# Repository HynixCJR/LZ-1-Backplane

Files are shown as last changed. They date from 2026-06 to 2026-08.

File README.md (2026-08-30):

# LAZARUS-1 Backplane PCB
LAZARUS-1 is a 2U rackmount server designed to support decommissioned laptops and SFF (Mini-ITX) desktop/server motherboards. The system consists of the following main components:
1. Sheet metal + 3D-printed chassis (TBD)
2. Backplane PCB (here)
3. [Front-panel breakout PCB](https://github.com/HynixCJR/serverv2_front_panel_breakout)

> [!WARNING]
> This PCB design is currently a work in progress. The initial schematic design has been created, and revisions have been made to most of the schematic; however, the PCB remains incomplete as of this time.

> [!TIP]
> I did not use any AI to write this documentation! All words you see here are written entirely by me (Matthew Kong).

This repository contains all files relevant to the LAZARUS-1 backplane PCB. The PCB supports the following features:
1. 12 x SATA HDDs/SSDs (3.5 inch, hot-swappable, 12V and 5V current monitoring/protection)
2. Internal USB-C to the laptop/desktop motherboard that provides PD 3.0 up to 100W, supports DP alt mode, as well as USB 3.2 Gen 2 data transfer to USB hub; branches off to:
    1. Internal 2 x USB 3.2 Gen 2 (10Gbps) RTL9210b NVMe/SATA M.2 SSD slots
    2. Internal SDXC MicroSD card slot
    3. 2 x downstream USB 2.0 ports
    4. MIPI CSI port; for video input to LicheeRV Nano
3. LicheeRV Nano for a custom NanoKVM implementation; takes video input from USB-C port and emulates USB HID keyboard and mouse to provide full IPKVM support through a single USB-C port
4. Temperature monitoring
5. 4 x 4-pin PWM fan headers
6. External touchscreen display support through a dedicated display SPI header
7. Real-time current/voltage monitoring for all subsystems
8. 3 x RP2354B microcontrollers for telemetry, subsystem control, and IC programming
9. 24 pin ATX PSU power input, supports standard full-sized ATX PSUs
10. External power on breakout board with LED indication and external USB hub (see: [front panel breakout](https://github.com/HynixCJR/serverv2_front_panel_breakout))

The system is designed to have low power draw while providing extensive enterprise-level feature sets to what would otherwise be e-waste laptop computers.

## Subsystems
Documentation has been written for most of the subsystems present on this PCB, and they can be found in the [docs/Subsystems](/docs/Subsystems).

### USB-C Data
- [TUSB1064 USB Switch Subsystem](docs/Subsystems/TUSB1064_USB_Switch.md): The subsystem that flips the TX/RX lines of the USB-C connector based on cable orientation
- [USB7205C USB 3.2 Gen 2 Hub](docs/Subsystems/USB7205C_USB3_Hub.md): The USB 3.2 Gen 2 Hub IC that allows 5 USB devices to be connected to the single USB-C port
- [USB2244i USB2.0->SDXC MicroSD](docs/Subsystems/USB2244i_USB_to_SD.md): The subsystem that converts the USB 2.0 signal from the USB7205C USB hub to SDXC for the MicroSD card slot
- RTL9210b: The subsystem that converts a USB3.2 Gen 2 signal to a PCIe Gen 3 lane, for use in the M.2 NVMe/SATA slots on this board
- UCS2113 & Downstream USB 2.0 ports: The subsystem that splits off the USB 2.0 lanes from the USB7205C hub into physical USB 2.0 ports, with port power protection

### Power Delivery
- [TPS65987D PD Controller Subsystem](docs/Subsystems/TPS65987D_PD_Controller.md): The subsystem that controls USB-C PD 3.0 and communicates configuration to the connected device
- [TPS55288 Buck-Boost Converter](docs/Subsystems/TPS55288_Buck_Boost_Converter.md): The buck-boost converter that converts the +12V ATX PSU rail to the voltage/current needed for USB-C PD 3.0

### IPKVM
- [PS176 DP->HDMI Converter](docs/Subsystems/PS176_DP_to_HDMI.md): The subsystem that converts the DisplayPort signal (from the USB-C connector, through DP alt mode) to HDMI
- [LT6911C HDMI to MIPI CSI Converter](docs/Subsystems/LT6911C_HDMI_to_CSI.md): The subsystem that converts the HDMI signal from the PS176 to a MIPI CSI signal, which goes off to the LicheeRV Nano

### SATA Subsystem
- TPS259540 and TPS259530: eFuses for the SATA 12V and 5V rails, preventing the power rails from sagging upon SATA drive hotswap events
- MCP6002: Operational amplifier that magnifies the analog current signal from the TPS2595x0 eFuses, so that the RP2354 MCUs can read the current drawn

### Telemetry
- [RP2354B MCU Subsystem](docs/Subsystems/LT6911C_HDMI_to_CSI.md): The MCU that performs telemetry, programs the PD controller and USB hub, and coordinates various system events (e.g., power on)
- [PAC1954 Power Monitoring](docs/Subsystems/PAC1954_Power_Monitor.md): The subsystem that monitors accumulated voltages and currents across the power rails for most components on this board, and outputs power data over I2C to the LicheeRV Nano
- [MCP9808 Temperature Monitoring](docs/Subsystems/MCP9808_Temperature_Monitor.md): The subsystem that monitors chassis temperature and outputs data over I2C to the LicheeRV Nano

### Front Panel I/O
- Display header
- Power LED and switch header

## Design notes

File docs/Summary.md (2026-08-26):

# LAZARUS-1 Backplane PCB Documentation
This is the WIP documentation for the LAZARUS-1 Backplane PCB documentation. The LAZARUS-1 is a 2U, 12x3.5 inch bay home server. To enable this, there is a relatively sophisticated backplane PCB to support all of additional functions of the system.

> Note: I did not use AI to write this documentation. This documentation is more intended as a way to verify my schematics/PCB layout before I waste $150 on a paperweight PCB than a public-facing documentation resource, but it can work as both if needed. :)

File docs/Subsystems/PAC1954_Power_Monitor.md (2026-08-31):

# PAC1954 Current Monitor Subsystem
## Preamble
LAZARUS-1 is designed to be a power efficient and power conscious server system. Part of being power conscious is actually knowing *how much* power the entire system and its subcomponents are drawing at any given time. Placing power monitors on all major subsystems is especially important because it allows for far greater granularity in the telemetry of the system; unlike conventional means of measuring power (i.e., a simple power meter between a wall outlet and the server), this setup enables the user to identify which specific components are drawing the most current, which can inform them of possible inefficiencies in their setup. For example, if IPKVM functionality is not needed, this monitoring setup can provide simple metrics on how much power is being wasted for that component, and thereby how much power can be saved by disabling it.

There are several ways of monitoring power, such as by measuring the voltage drop across a shunt resistor, by using a hall effect sensor, and by using a current transformer. The shunt resistor design is inherently wasteful, as it forces the resistor to dissipate power as heat when stepping down the voltage. However, it is significantly more accurate that any other method, while being less bulky and costly. Moreover, the wasted power can be minimized by using smaller current sense resistors (and thus, current monitors that support this functionality).

The PAC1954 was mainly chosen for this purpose because:
1. It is a four channel shunt resistor voltage/current monitor, meaning fewer ICs are actually required for power monitoring.
2. It can technically support smaller current sense resistor values than calculated, at the expense of resolution and higher error - for high current rails, the lower dissipated power is more important than this downside.
3. It performs power calculations and accumulation automatically, and sends this pre-calculated value over I2C, which is nice since this device interfaces with the LicheeRV Nano directly (thus requiring less programming on the LicheeRV Nano).
4. It's a Microchip product, so I can source it for free from Microchip's free sample program. <3

## Description
The PAC1954 is a four-channel current-sense and voltage monitor IC from Microchip that outputs over I2C. It performs power calculations automatically, and accumulates values to calculate a rolling average. It comes in a small 3x3mm VQFN package, and requires external current sense resistors to function. The PAC1954-1 variant can only measure high-side power (between voltage source and load), while the PAC1954-2 can also measure low-side (between load and GND). For this application, only high-side is used, and so either variant is useable.

## Revision Progress

| Stages | PAC1954_PSU_PD | PAC1954_FANS | PAC1954_IPKVM | PAC1954_HUB  |
| --- | :---: | --- | --- | --- |
| Initial Design |  ✅ 2026-07-10  | ✅ 2026-07-12 | ✅ 2026-07-11  | ✅ 2026-07-12 |
| Basic Function Review/Documentation  |  ✅ 2026-08-25  | ✅ 2026-08-19 | ✅ 2026-08-30  | |
| Extended Design Review/Documentation | | | | |
| Initial PCB layout | | | | |

## Design

### Input Power
The PAC1954 can operate with an input supply of +2.7V to +5V. For the LAZARUS-1 PCB, +3.3V is chosen for this subsystem because it lands comfortably in the middle of that range, and can be easily supplied by the ATX PSU +3.3V rail. Per the [PAC1954 Click reference design schematic](https://download.mikroe.com/documents/add-on-boards/click/pac1954_click/pac1954-click-schematic-v100.pdf), a 4.7uF and 100nF decoupling capacitor are placed near the VDD pin to filter noise.

### SLOW/ALERT1 Pin
> *Pin: SLOW/ALERT (1)*

By default, if Pin 1 is forced high, the PAC1954 enters slow sampling mode, where it only samples the current 8 times per second. Otherwise, if it's pulled low, it samples at 1024 samples per second. This pin can also be programmed as ALERT1, which is a programmable GPIO output pin. ALERT1 is not really necessary, since there are already pre-existing functions for each subsystem to prevent overcurrent where necessary; the system will only gather telemetry through polling over I2C.

Slow mode is used in this design because the fast sampling rate is simply not necessary; the power monitoring is not tied to any critical system functions, and so very brief (<1/8th second) transients aren't that important to capture. Moreover, slow mode consumes 3% the typical current of default mode. This amounts to a mere 1.26mW power savings per PAC1954, which is basically nothing in the grand scheme of things, but is still somewhat meaningful (in spirit!). It also brings the typical power consumption down to a measly 0.0396mW, which is kinda cool.

### I2C Pins
> *Pins: SCL (4), SDA (5), ADDRSEL (6)*

The four PAC1954's on the LAZARUS-1 PCB are connected to the LicheeRV Nano's I2C1 interface, along with the MCP9808 temperature sensor, as I2C slaves. This is just a standard I2C interface, and so 49.9kΩ pull up resistors are added for every PAC1954 on the PCB. This amounts to a total effective resistance of 12.5kΩ, which is a relatively standard resistance.

The slaves addresses of the PAC1954's must be adjusted to ensure that multiple PAC1954's don't interfere with each other over I2C. Luckily, there are 16 possible slave addresses that can be chosen from, and they can be chosen through a pull down resistor between the ADDRSEL pin and GND. Below are the addresses and pull down resistor values chosen for this design:

| | PAC1954_PSU_PD | PAC1954_FANS | PAC1954_IPKVM | PAC1954_HUB |
| --- | --- | --- | --- | --- |
| Resistor | Tied to GND | Tied to +3.3V | 499Ω ± 1% | 806Ω ± 1% |
| Address  | `0010 000 (R/W)` | `0011 111 (R/W)` | `0010 001 (R/W)` | `0010 010 (R/W)` |

This shouldn't collide with the single MCP9808, which has an I2C address of `0011000`. PAC1954_PSU_PD is tied to GND, and PAC1954_FANS to +3.3V, to save space on the PCB.

### PWRDN# 
> *Pin: PWRDN# (16)*

The PWRDN# pin is an active low disable (or alternatively, an active high enable). The PAC1954 barely consumes any power, and shuts off along with the PSU's +3.3V rail, so there isn't really a reason to tie this to any GPIO pin of an MCU. So, it is simply permanently pulled high by a 10kΩ resistor.

### GPIO/ALERT2 Pin
> *Pin: GPIO/ALERT2 (15)*

The PAC1954 has a GPIO input or ALERT output pin on pin 16, which can be programmed over I2C. However, as detailed in [SLOW/ALERT1 Pin](#slow/alert1-pin) description, additional GPIO is not needed for this application, so it is simply tied to GND through a 10kΩ resistor.

### SENSE Pins and Current Sense Resistors
> *Pins: SENSEx+, SENSEx-*

On the PAC1954, there are four current/voltage sense channels, which equates to eight SENSE pins (four `+`, four `-`). In a high-side configuration, which is used in this design, the `+` pin is connected directly to the input supply, the `-` pin is connected to the load, and a current sense resistor bridges the `+` and `-` pins together.

The value of the current sense resistor can be calculated by:
```
R_SENSE = FSR / I_MAX
```

...where `I_MAX` is the maximum current drawn by the subsystem, and `FSR` is 100mV.
> Note: `FSR` is set to 100mV unidirectional by default, and that is used on the LAZARUS-1 PCB.

However, `I_MAX` for certain subsystems may be far greater than what is typically drawn; for example, `I_MAX` for the +12V, +5V, and +3.3V rails is calculated for the absolute worst-case possible scenario, where USB-C PD is sustained at 100W, all 12 SATA ports are connected to HDDs that are actively being spun up, and all other subsystems are completely maxxed out. Realistically this will never happen, but `I_MAX` is still used, as a lower `I_MAX` would result in a larger current sense resistor (and thereby higher power dissipation). Moreover, it is still safe; the only downside would be lower precision, but with 16 total bits the actual precision still remains good enough for this application. For example, for the worst case scenario for the +12V rail (32A), the measurement is still precise down to 0.5mA (or 5.9mW). This is largely negligible for basic telemetry.

The specific subsystems monitored by the PAC1954's, and which PAC1954 they are monitored by, are detailed in the table below.

| PAC1954 number | Subsystem/voltage | Max current | Typical Current | Sense Resistor | Power wasted (typ) |
| --- | --- | --- | --- | --- | --- |
| 0 | Fans/+12V | 500mA | ~50mA | 200mΩ ±1% | ~0.5mW |
| 0 | PSU/+5V | 40A | ~4.8A | 5mΩ ±5% | ~24mW |
| 0 | PSU/+12V | 20A | ~8A | 2.5mΩ ±1% | ~20mW |
| 0 | PSU/+3V3 | 1.47A | ~0.5A | 68mΩ ±1% | ~34mW |
| 1 | PS176/+3V3 | 196mA | 30uA | 510mΩ ±5% | ~15.3uW |
| 1 | LT6911C/+3V3 | 196mA | 196mA | 510mΩ ±5% | ~100mW |
| 1 | Display/+3V3 | 47mA | 24mA | 2Ω ±1% | ~48mW |
| 1 | LicheeRV Nano/+5V | 1.1A | 200mA | 90mΩ ±1% | ~18mW |
| 2 | | | | | |
| 2 | | | | | |
| 2 | | | | | |
| 2 | | | | | |
| 3 | Fans/+12V | 500mA | ~50mA | 200mΩ ±1% | ~0.5mW |
| 3 | Fans/+12V | 500mA | ~50mA | 200mΩ ±1% | ~0.5mW |
| 3 | Fans/+12V | 500mA | ~50mA | 200mΩ ±1% | ~0.5mW |
| 3 | Fans/+12V | 500mA | ~50mA | 200mΩ ±1% | ~0.5mW |

> *Note: 0 = PAC1954_PSU_PD, 1 = PAC1954_IPKVM, 2 = PAC1954_HUB, 3 = PAC1954_FANS*

#### Subsystem Current Calculations
##### 1. Global +12V rail:
- `(12 HDDs × 2.0A) + 9.2A (PD) + (5 fans × 0.5A) = 35.7A`
- With 10% safety margin: `35.7A * 1.10 = ~39.27A`
- Sense resistor: `100mV / 39.27A = ~2.5mΩ`
- Actual max current: **~40A**
- Realistic typical current (active use, 12 HDDs, 50W laptop): `(12 HDDs × 0.25A) + 4.2A (PD) + (5 fans × 0.16A) = 8A`
##### 2. Global +5V rail:
- `(12 HDDs × 1.0A) + 0.6A (PD CTRL) + 3 × 1.5A (Panel) = 17.1A`
- With 10% safety margin: `17.1A × 1.10 = ~18.81A`
- Sense resistor: `100mV / 18.81A = ~5mΩ`
- Actual max current: **~20A**
- Realistic typical current (active use, 12 HDDs, no panel use, no active PD cable): `12 HDDs × 0.4A = 4.8A`

##### 3. Global +3V3 rail:
- `0.008A (PD CTRL) + (3 flash × 0.025A) + (3 RP2354 × 0.025A) + 0.18A (MUX) + 0.2A (HUB) + 0.15A (SD) + 0.173A (PS176) + 0.188A (LT6911C) + 0.3A (DISP) = 1.349A`
- With 10% safety margin: `1.349A × 1.10 = ~1.48A`
- Sense resistor: `100mV / 1.48A = ~68mΩ`
- Actual max current: **1.47A**
- Realistic typical current (active use, display off, IPKVM off): ~0.5A

##### 4. PS176
- Per datasheet, at HDMI output 5.94Gbps, there is a normal supply current of `18.5mA` at `+3.3V`, and `432.2mA` at `1.2V`.
- This system uses an MCP1602 buck converter, which has ~80% efficiency with `432.2mA` drawn at `1.2V` output.
- So, total current is: `1.2 × 432.2mA × 1.2V / 3.3V + 18.5mA = 144.2mA`
- With 10% margin, that comes out to `144.2mA × 1.10 = 158.62mA`
- Sense resistor: `100mV / 158.62mA = ~625mΩ`
- But `510mΩ` is much cheaper! So we get actual max current: **196mA**
- When shut down by RP2354, current drawn is `30uA`

##### 4. LT6911C
- Per datasheet, at 1080p 60Hz, the LT6911C draws: `56mA` at `+3.3V`, and `306mA` at `+1.2V`.
- This subsystem uses the same MCP1602 as the PS176, so assuming 80% efficiency, the total current drawn is `1.2 × 306mA × 1.2V / 3.3V + 56mA = 189.5mA`
- With 10% margin: `189.5 × 1.10 = 208.5mA`
- Sense resistor: `100mV / 208.5mA = ~480mΩ`
- But `510mΩ` is already being used, so we get actual max current: **196mA**
- The system does not have a power down mode specified in the datasheet, so assume that max current draw is equal to the typical current draw.

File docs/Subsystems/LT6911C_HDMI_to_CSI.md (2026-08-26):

# LT6911C HDMI to MIPI CSI Converter Subsystem
## Preamble
The LT6911C is used in the pathway between the laptop and the IPKVM; it converts the HDMI signal from the PS176 into a MIPI CSI signal that can be used by the LicheeRV Nano to deliver video output over IP, thus enabling IPKVM functionality. DisplayPort to MIPI CSI ICs do exist, and would theoretically use significantly less board space and consume slightly less power; however, these ICs would require substantial software configuration. The LT6911C is used in the official NanoKVM, so the same device tree and firmware can be used, whereas chips like the ITE IT6510 or LT7911D would require custom firmware (that is not publicly available). Hence, the LT6911C was chosen.

This step was originally occupied by the TC358743XBG; however, it was replaced with the LT6911C because the TC358743XBG uses a BGA footprint, which is substantially harder to solder and design for.

## Description
The [LT6911C](https://github.com/HynixCJR/serverv2_backplane/blob/main/datasheets/LT6911C_HDMI_to_CSI_System/LT6911C_HDMI_to_CSI_datasheet.pdf) is an HDMI 1.4 to MIPI CSI converter IC. In the LAZARUS-1 Backplane PCB, it is used to convert the HDMI signal from the PS176 (whose video signal originates from the connected host device) to a MIPI CSI signal that can be interpreted by the LicheeRV Nano. The LicheeRV Nano can use this display signal to enable IPKVM capabilities.

Unfortunately, the LT6911C is not very well documented, with only proprietary firmware options. Furthermore, there are no official reference designs or schematics, and the (leaked) datasheet is quite barebones. So, the design of the LT6911C circuit used on this PCB is largely reverse engineered from the publicly released [3D model](https://github.com/HynixCJR/serverv2_backplane/blob/main/datasheets/LT6911C_HDMI_to_CSI_system/LT6911C_Sipeed_3D_model.html) of the official adapter HDMI->CSI adapter board used in Sipeed's NanoKVM Lite. Modifications were made to this design using (generally) cheaper components and to adapt it to the embedded architecture of the Backplane PCB. This was all cross-referenced with an open source [LT6911C HDMI->MIPI DSI board](https://github.com/HynixCJR/serverv2_backplane/blob/main/datasheets/LT6911C_HDMI_to_CSI_system/LT6911C_HDMI_to_DSI_reference_schematic.pdf) designed by Hyper12 on [OSHWHub](https://oshwhub.com/cnflysky/h2d_lt6911c). Unfortunately, this is implemented for DSI rather than MIPI CSI, so an exact copy wasn't possible.

The design very closely mirrors the official HDMI->CSI adapter used in the NanoKVM Lite, as the NanoKVM's binary file for this adapter is unfortunately the only way to use the LT6911C for this purpose without a license.

## Revision Progress

| Stages | LT6911C | MCP1602 | Logic Level Shifter |
| --- | :---: | :---: | --- |
| Initial Design | ✅ 2026-07-20 | ✅ 2026-07-20 | ✅ 2026-07-20 |
| Basic Function Review/Documentation  | ✅ 2026-07-25 | ✅ 2026-07-22 | ✅ 2026-07-23 |
| Extended Design Review/Documentation | | | |
| Initial PCB layout | | | |

## Design

### Power
There are three voltage rails used in this design: 3.3V, 1.8V, and 1.2V. The 3.3V and 1.2V rails are the main power rails, whereas the 1.8V rail is only for logic interfacing with the MIPI CSI connector.

In the official design, 3.3V is supplied to the LT6911C through the CSI connector by the LicheeRV Nano. To prevent back feeding, the 3.3V pin on the CSI connector is left floating, and the ATX PSU's 3.3V rail supplied 3.3V to the LT6911C. The official design does not have any filtering for the 3.3V rail (other than decoupling capacitors), but the reference schematic passes the rail through a 120Ω@100MHz ferrite bead with 30mΩ DCR and 3A current rating before supplying the IC. Thus, a ferrite bead with matching impedence at 100MHz but lower DCR and higher current rating is used in this design. This bead was chosen because it was cheaper with (supposedly) better specifications.

Four 100nF decoupling capacitors are included on the 3.3V rail in the official 3D model, along with one single 10uF decoupling capacitor. As such, this design also uses these capacitor values and quantities for decoupling on the 3.3V rail.

The 1.2V rail is generated by the MCP1602 buck converter, which is fixed to supply 1.2V and max 500mA. Per the datasheet, the max 1.2V supply current used by the LT6911C is 306mA at 1080p 60Hz MIPI output (which is the maximum supported by the NanoKVM), which is within spec for the buck converter. The design of the MCP1602 circuit is the same as in the PS176 subsystem; it is essentially unchanged from Figure 6-3 in its datasheet.

Before being supplied to the LT6911C, the 1.2V rail passes through the same ferrite bead as the 3.3V rail. This matches the reference schematic and helps filter out high frequency noise on this rail.

In the official 3D model, four 100nF decoupling capacitors are included on the 1.2V rail, along with two 10uF decoupling capacitors. However, since the reference schematic uses six 100nF decoupling capacitors instead of four, this design uses six 100nF + two 10uF decoupling capacitors on the 1.2V rail.

To supply the 1.8V needed for the 1.8V logic of the MIPI CSI interface, a simple MCP1700 LDO is used to step down the 3.3V rail to 1.8V. This is not as efficient as a buck converter, but it uses a much smaller footprint, and the current supplied is very low anyways because the rail is only used for logic. The MCP1700T-1802E used in this design is fixed to 1.8V, and so only two 1uF capacitors (one on the input pin and one on the output pin, per the datasheet) are required.

---
### Crystal Oscillator
> *Pins: XTLI (64), XTLO (63)*

A 27MHz crystal oscillator is used in this subsystem to control timing. The datasheet does only mentions that a 27MHz, 100ppm crystal is needed (with no further elaboration), so this design decision is based on the 3D model. Below is a comparison table of the oscillator used in this design vs. the one used in the 3D model.

| LCSC Part Number | Used by: | Load Capacitance | Frequency Stability | Frequency Tolerance | ESR |
| --- | --- | --- | --- | --- | --- |
| C255890 | 3D Model | 8pF | ±10ppm | ±10ppm | 60Ω |
| C37635384 | LAZARUS-1 Backplane PCB | 9pF | ±10ppm | ±10ppm | 30Ω |

For frequency stability, frequency tolerance, and ESR, lower values are generally better. the oscillator used in this design is therefore a good choice. However, the load capacitance is not the same, and so different capacitor values are used.

> Note: the reference design uses 18pF capacitors, which seems far too high...? So 10pF capacitors are used in this design, which nets a stray board capacitance of 4pF.

---
### CSI I2C Pins
> *Pins: CSCL (21), CSDA (22)*

These pins form the I2C channel that connects to the I2C pins on the FPC connector. However, coming out of the LT6911C, they use 3.3V logic, whereas the Lichee RV Nano accepts 1.8V logic on the I2C pins of its FPC connector (per the official Lichee RV Nano schematic). As such, a level shifter is needed for these pins.

The level shifter used in this design is a simple enhancement MOSFET-based implementation that is [detailed here](https://www.digikey.ca/en/blog/logic-level-shifting-basics); in essence, the higher voltage logic (3.3V, from the LT6911C) is connected to the drain, the 1.8V LDO is connected to the gate, and the lower voltage logic (1.8V, to the CSI connector) is connected to the source. Pull up resistors to the respective logic voltages are included on the drain and source. This enables the system to abide by the following behaviour:

| Scenario | Gate voltage (LDO, 1.8V) | Drain voltage (3.3V I2C, LT6911C side) | Source voltage (1.8V, CSI side) |
| --- | --- | --- | --- |
| Default state (no side asserted) | 1.8V | 3.3V (from pull up) | 1.8V (from pull up) |
| Drain -> 0V | 1.8V | 0V | -> 0V (MOSFET internal diode opens, so source matches drain) |
| Source -> 0V | 1.8V | -> 0V (V_GS > V_th, so MOSFET turns on and current flows, so drain matches source) | 0V |

In effect, the logic on each side will match. This is essentially the same design as is used on the official NanoKVM Lite LT6911C board. However, in this design, this is accomplished with a 2 N-channel enhancement MOSFET ([EM6K7T2R](https://github.com/HynixCJR/serverv2_backplane/blob/main/datasheets/LT6911C_HDMI_to_CSI_system/ROHM_EM6K7T2R_Nch_MOSFET_datasheet.pdf)), as opposed to the official design, which uses a similar MOSFET ([DMN31D5UDJ](https://www.diodes.com/assets/Datasheets/DMN31D5UDJ.pdf)). The EM6K7T2R has the same max V_GS(th) of 1.0V (so the MOSFET should still turn on when the source is pulled low), but with lower R_DS(on) at 1.8V. However, the capacitance is higher (25pF vs. 22.6pF), but it should still be fine enough, as long as the FPC cable is short enough (which it will be, I think).

A 2kΩ pull up resistor is placed on the SCL/SDA lines on the LT6911C side, but the official design does not include them on the FPC side. This is likely because there are already 5.1kΩ pull up resistors on those pins on the LicheeRV Nano, per its schematic. However, just in case they aren't present, empty footprints for 10kΩ resistors are added to the I2C lines on the FPC side.

---
### INTIO/GPIO5 Pin
> *Pin: INTIO_GPIO5 (26)*

This pin is rather confusing because the datasheet just labels this pin as "GPIO", with no further explanation. Moreover, the LicheeRV Nano schematic wires up pin 17 of the CSI connector (which INTIO_GPIO5 is connected to) to "CAM_IO0", despite the LT6911C here not serving as a camera. In fact, the table below details the configuration description from the datasheet:

| Camera + FPC | CAM_IO0  | CAM_IO1 |
| --- | --- | --- |
| Sipeed GC4653 + 70416 FPC | RESET | MCLK(connect to MIPI 0N with R72 by default) |
| Sipeed OS04A10 + same direction FPC | RESET | NC |
| Raspberry Pi camera (level matching<br>required) | Power EN | LED Indicator |

There is no mention of the NanoKVM's use of this pin. Additionally, CAM_IO1 (pin 18 of the CSI connector) is just left as NC on Sipeed's official 3D model of the LT6911C PCB. None of these pins are mentioned anywhere in the official documentation.

Regardless, this design mirrors the implementation in Sipeed's official 3D model of the LT6911C PCB. Just like with the I2C pins, a MOSFET level shifter is used - which, in this case, is a 2N7002 because (presumably) this GPIO pin is not as fast as the I2C pins. The INTIO_GPIO5 pin connects to the drain of the 2N7002 with a pull up to 3.3V, pin 17 of the CSI connector connects to the source pin with a pull up to 1.8V, and the gate is connected to the 1.8V LDO. Same general config as the I2C pins in this design. This mirrors the official design almost exactly; however, the purpose of this pin is still under question. Unfortunately, this question may never be answered because the firmware is proprietary. Great!

---
### Other Pins
> *Pins: RSVD (17, 18), SLEEP_33 (19), RST_N (20)*

- RSVD (17, 18): The datasheet says to leave these pins floating, but the official implementation pulls these down to GND using a 100kΩ resistor. Thus, the footprint of 100kΩ resistors are placed, and can be left unsoldered if the pins need to be floating.
- SLEEP_33 (19): Labelled as "External Sleep Mode Control Signal" in the datasheet; pulled low by a 100k resistor to prevent external sleep control, as in the official implementation.
- RST_N (20): Active low reset for the LT6911C. Pulled to 3.3V by a 10kΩ resistor to prevent random resets; same as official implementation. A 2.2uF capacitor is also added to filter noise.

---
### I2S Pins
> *Pins: IIS_WS (27), IIS_SCLK (28), IIS_MCLK (29), IIS_D0/SPDIF (31)*

These pins are used for audio output; however, they are not used in this design, as the LicheeRV Nano does not support I2S audio input (the I2S is used up by the microphone). So, just like in the official implementation, these pins are left floating.

---
### HDMI Input Pins
> *Pins: HDMI_CP (3), HDMI_CN (2), HDMI_xP/HDMI_xN, HDMI_SCL (16), HDMI_SDA (15), HDMI_HPD (23)*

HDMI uses 3 TMDS data lanes (HDMI_xP and HDMI_xN), 1 TMDS clock lane (HDMI_CP and HDMI_CN), 1 CEC pin for control (CEC), 1 HPD pin to signal connection (HDMI_HPD), 1 I2C line (HDMI_SCL and HDMI_SDA), and 5V/GND pins. The LT6911C doesn't seem to have a pin dedicated to CEC, so on the PS176, that pin is left floating, which is fine for functionality since it is optional for manufacturers (I think). Additionally, 5V and GND is supplied by the ATX PSU.

In the official design, the I2C traces are connected to the HDMI port, with 33kΩ pull ups to 5V, and a diode between the pull ups and 5V (presumably) to prevent back feeding. However, the diode was removed in this design because the HDMI traces go straight to the PS176 without an intermediary HDMI port/receptacle. Moreover, the pull ups on the LT6911C side were removed, since the LT6911C will physically be close enough to the PS176 that additional pull ups will not be needed. This saves on board space, which is desperately needed.

The HDMI clock and data lanes are wired directly to their corresponding pins on the LT6911C. On the official design, there is a TVS diode on each trace to protect against ESD, but they are also not needed in this design because of a lack of a physical port.

On the official design, the HPD trace goes straight to the HDMI port's HPD pin. The datasheet does not say if there is an internal pull up, but the reference schematic includes a 2kΩ pull up to 5V despite its absence in the official 3D model. Thus, a 2kΩ pull up resistor is included; if it is not needed, it can be excluded in assembly.

---
### MIPI CSI Pins
There are several MIPI lanes that are left as NC, as the LT6911C supports more channels than are available on the FPC connector. Below is a table of the pins and their descriptions:

| Channel name (datasheet) | Pin number | Description | Connection on PCB |
| --- | --- | --- | --- |
| M0_L3_1 | 49 (+), 50 (-) | MIPI TX Port1/Lane0 | CSI_0P (CSI pin 3)/CSI_0N (CSI pin 2) |
| M1_LCK_1 | 51 (+), 52 (-) | MIPI TX Port1/Lane1 | CSI_1P (CSI pin 6)/CSI_1N (CSI pin 5) |
| M2_L1_1 | 55 (+), 56 (-) | MIPI TX Port1/Lane2 | CSI_2P (CSI pin 12)/CSI_2N (CSI pin 11) |
| M3_L0_1 | 57 (+), 58 (-) | MIPI TX Port1/Lane3 | CSI_3P (CSI pin 15)/CSI_3N (CSI pin 14) |
| MCK_L2_1 | 53 (+), 54 (-) | MIPI TX Port1/Clock Channel Output | CSI_CP (CSI pin 9)/CSI_3N (CSI pin 8) |

The rest of the pins are left as NC; in the reference schematic, the remaining pins are routed to the FPC connector, which has more pins than the one used in this design. The unused pins are for the second port (which, for some reason, is labelled as "port 3" in the datasheet), presumably to allow for multiple display connections. This single port configuration is exactly as depicted in the official 3D model.

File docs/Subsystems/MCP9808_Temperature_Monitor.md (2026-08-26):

# MCP9808 Temperature Sensor Subsystem
## Preamble
A simple temperature sensor is helpful to include on the board to track chassis temperatures during operation. This can help inform the user if the chassis is overheating, which is important because the LAZARUS-1 PCB is designed to supply up to 100W to the laptop and up to ~120W to HDDs. The MCP9808 is a good choice for this mainly because it is very easy to source (thanks Microchip!), communicates over a simple I2C interface, has a small DFN package, and requires very few external components to function. In fact, this design literally only uses one bypass capacitor; it doesn't even need pull up resistors on the I2C traces because it shares an I2C bus with the PAC1954 current monitors, which each have their own pull ups.

## Description
The MCP9808 is a digital temperature sensor. It reads temperatures from -40°C to 100°C with a typical accuracy of just ±0.25°C, and outputs the temperature readings digitally over I2C. It consumes very little current during operation (200uA typical), and operates on +2.7V to +5.5V.

## Revision Progress

| Stages | MCP9808 |
| --- | :---: |
| Initial Design | ✅ 2026-07-09 |
| Basic Function Review/Documentation  | ✅ 2026-08-16 |
| Extended Design Review/Documentation | |
| Initial PCB layout | |

## Design

### Power
> *Pin: VDD (8)*

The VDD pin takes in any voltage input from +2.7V to +5.5V, with no typical or recommended value specified in the datasheet. So, this design uses the +3.3V rail from the ATX PSU; this fits comfortably within that range. Per the datasheet, a 100nF bypass capacitor is placed on this pin.

### I2C Interface
> *Pins: SDA (1), SCL (2), A0 (7), A1 (6), A2 (5)*

The MCP9808 communicates directly to the LicheeRV Nano through its I2C1 interface as a slave device. The I2C1 channel is shared between the MCP9808 temperature sensor and the PAC1954 current monitors. This presents a few slight complications.
1. Pull up resistors: SDA and SCL pins for the PAC1954 all have 49.9kΩ pull up resistors to enable functionality. This approach is used over a single pull up system because the sensors are placed all over the board, and not close to each other, causing the trace length to be quite long. Since there are four PAC1954's on the board, the total effective resistance is 12.5kΩ, which leads to 264uA current being drawn for logic. This can lead to self-heating, though the datasheet mentions that at 500uA max current draw, the self heating is only +0.2°C for the DFN package. This is fairly negligible for the purposes of the LAZARUS-1 PCB.
2. I2C slave addresses: Since there are already four other slaves devices (PAC1954) on the same I2C channel, the I2C address of the MCP9808 must not collide with any of the other devices. Luckily, the address can be set by the A0, A1, and A2 pins; when they are all grounded, the address is `0011000` or `0x18`. This will almost certainly not collide with any of the PAC1954's, as their addresses are all `0010xxx`.

### ALERT Pin
> *Pin: Alert (3)*

The MCP9808 has an open-drain temperature alert pin to signal when the temperature sensed reaches or surpasses a user-programmable limit. This is not used for the LAZARUS-1 PCB, as this subsystem is only intended for basic telemetry. So, this pin is floated.

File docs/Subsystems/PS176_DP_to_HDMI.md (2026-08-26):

# PS176 DP to HDMI Subsystem
## Preamble
The PS176 is used in the pathway between the laptop and the IPKVM; it converts the DisplayPort signal (from the USB-C port, through DP Alt-mode) to HDMI, which is then converted by the LT6911C to MIPI CSI to be interpreted by the LicheeRV Nano SBC. DisplayPort to MIPI CSI ICs do exist, and would theoretically use significantly less board space and consume slightly less power; however, these ICs would require substantial software configuration. The LT6911C is used in the official NanoKVM, so the same device tree and firmware can be used, whereas chips like the ITE IT6510 or LT7911D would require custom firmware (that is not publicly available). Hence, the PS176 is required as an additional step to convert the DisplayPort to HDMI.

This specific chip was chosen for the following reasons:
1. There is already a pre-existing open source design by lemon_wifi on [OSHWHub](https://oshwhub.com/lemon_wifi/PS176), which does not require significant modification to work in this embedded system.
2. Unlike the TI SN65DP159, which is a passive retimer that requires dual-mode DisplayPort (DP++), the PS176 is an active chip that works with any native DisplayPort port. This is important because USB-C DP Alt-mode generally does not support dual mode operation, and hence the SN65DP159 would not function in this case. This is rather unfortunate because TI's documentation and openness is unmatched by any of the other chips contending for use in this step.
3. The PS176 is rather cheap; it is available for <$2 CAD + shipping on Aliexpress, and does not require any expensive external components.
4. Despite the PS196 being newer and more advanced (supporting higher resolutions, using less power), the PS176 was still chosen because it is more purchasable in individual quantities. Additionally, the PS176 uses a smaller footprint.

## Description
The [PS176](https://github.com/HynixCJR/serverv2_backplane/blob/main/datasheets/PS176_DP_to_HDMI_System/PS176_DP_to_HDMI_Datasheet.pdf) is a native DisplayPort 1.2a to HDMI 2.0 converter IC that does not rely on DP++ support. In this backplane PCB, it's used to convert the DP signal from the TUSB1064 switch (and thus from the upstream USB-C port, connected to the laptop) to a native HDMI signal, which is then converted to a CSI to be used as an input to the Lichee RV Nano for IPKVM purposes.

This design is largely based on the [reference design](https://github.com/HynixCJR/serverv2_backplane/blob/main/datasheets/PS176_DP_to_HDMI_System/PS176_Reference_Schematic.pdf), which is an open source design created by [lemon_wifi on OSHWHUB](https://oshwhub.com/lemon_wifi/PS176). However, changes were made to suit the embedded design (i.e., no ports) of this subsystem.

## Revision Progress

| Stages | PS176 | MCP1602 |
| --- | :---: | :---: |
| Initial Design | ✅ 2026-05-02 | ✅ 2026-07-21 |
| Basic Function Review/Documentation  | ✅ 2026-07-21 | ✅ 2026-07-21 |
| Extended Design Review/Documentation | | |
| Initial PCB layout | | |

## Design

### Power
The PS176 uses three voltage rails: 5V, 3.3V, and 1.2V. However, it draws most of its current (per the datasheet) from the 1.2V rail. Since this system is embedded onto the backplane PCB, no additional power connectors are needed for the 3.3V rail or 5V rail; the PS176 can simply draw from the main 3.3V or 5V ATX PSU rails. However, 1.2V is supplied using a simple 3.3V->1.2V buck converter. 5V is only used for HDMI I2C pull up voltages.

To supply 1.2V, the `MCP1602-120I_MF`, which is a fixed 1.2V output variant of the [MCP1602](https://github.com/HynixCJR/serverv2_backplane/blob/main/datasheets/PS176_DP_to_HDMI_System/MCP1602_Buck_Converter.pdf), steps down the 3.3V rail to 1.2V. The circuit implementation is essentially unchanged from Figure 6-3 in its datasheet, since the total current consumption of the PS176 is ~350mA @ 1.2V, which is less than the design's 1.2V @ 500mA spec. The PG pin is pulled up to 3.3V by a 10k resistor, but isn't tied to any MCU GPIO pin to make routing easier. To ensure that the buck converter is only active when the PS176 is in use, the SHDN# pin is tied to pin 37 (VDD12_ON) of the PS176.

In accordance with the reference design, each (pair of) voltage input pins on the PS176 has a 330Ω@100MHz ferrite bead in series. This is used to further filter high frequency noise. 

In accordance with the reference design, all voltage rails (including those outputted by the PS176 itself) have bypass capacitors to filter noise.

---
### DP Input Pins
DisplayPort uses 4 differential data transfer lanes (DPx+ and DPx-), 1 bidirectional differential AUX lane for config/EDID/DPCD communication (AUX+ and AUX-), 1 single HPD signal to signal connection (DP_HPD), and GND/3.3V pins. Since the subsystem is embedded, the GND and 3.3V pins are supplied by the main ATX PSU voltage rails.

Per the DisplayPort specification, 100nF capacitors are required in series on each differential data transfer wire (DPx, AUX) for AC coupling. As they are included in the TUSB1064 subsystem, they are not needed in the PS176 subsystem.

Pull up resistors are included, per the reference design, on the AUX and HPD wires. However, since the 100nF capacitors are included in the TUSB1064 subsystem, the 1M pull down/pull up resistors on AUX+ and AUX- respectively are also included in that subsystem, and are thus not represented on the PS176 schematic.

A 1kΩ resistor is included in series on the DP_HPD pin for power sequencing protection, in accordance with the reference design. If this is not needed, or if the resistor value is incorrect, it can be swapped for a 0Ω or other resistance value, as the HPD pin is not high speed.

---
### HDMI Output Pins
HDMI uses 3 TMDS data lanes (HDMI_xP and HDMI_xN), 1 TMDS clock lane (HDMI_CP and HDMI_CN), 1 CEC pin for control (CEC), 1 HPD pin to signal connection (HDMI_HPD), 1 I2C line (HDMI_SCL and HDMI_SDA), and 5V/GND pins. Since the subsystem is embedded, the GND and 5V pins are supplied by the main ATX PSU voltage rails. However 2kΩ pull up resistors (to 5V) on the I2C line are still required per the HDMI specification. This is paired with a 33kΩ pull up resistor in the LT6911C subsystem, which receives the HDMI output of the PS176.

The TMDS data lanes do not require additional components, such as clamps/diodes or other ESD protection, as forfeiting the physical HDMI port makes them largely unnecessary. The reference design only includes diodes on the 5V line; however, they are excluded from this design since there is no physical HDMI port.

The CEC pin is not used by the LT6911C, and so it is left floating.

---
### Control I2C
> *Pins: CSCL (29), CSDA (28), I2C_ADDR (3)*

These pins are for the control I2C slave line, which is used for debugging. The pins are pulled up to 3.3V by a 4.7k pull up resistor, with no further connection to an MCU to simplify routing (they aren't necessary for functionality). Pads may be included on these traces for debugging purposes.

The I2C_ADDR pin is pulled high by a 4.7kΩ resistor to 3.3V, which sets the I2C address of the CSCL and CSDA line to `90h – 9Fh, D0h – DFh`, per the datasheet.

---
### Crystal Oscillator
> *Pins: XTLI (26), XTLO (25)*

A 27MHz crystal oscillator is used in this subsystem to control timing. The datasheet does not mention what frequency or other specifications are required for the crystal, so this design decision is based on the reference design. Below is a comparison table of the oscillator used in this design vs. the one used in the reference design.

| LCSC Part Number | Used by: | Load Capacitance | Frequency Stability | Frequency Tolerance | ESR |
| --- | --- | --- | --- | --- | --- |
| C156249 | Reference design | 8pF | ±30ppm | ±20ppm | 50Ω |
| C37635384 | LAZARUS-1 Backplane PCB | 9pF | ±10ppm | ±10ppm | 30Ω |

For frequency stability, frequency tolerance, and ESR, lower values are generally better. the oscillator used in this design is therefore a good choice. However, the load capacitance is not the same, and so different capacitor values are used.

The reference design also omits the usual 1MΩ resistor between the oscillator pins, though the datasheet does not mention anything about internal resistance between the two pins. So, a 1MΩ resistor footprint is added, but labelled as Do Not Populate (DNP).

> Note: the reference design uses 15pF capacitors, which seems to imply that there is only ~0.5pF stray board capacitance. This seems too low, so 10pF capacitors are used in this design, which nets a stray board capacitance of 4pF.

---
### AUXDCx
> *Pins: AUXDCP (32), AUXDCN (31)*

These two pins are labelled as "DP source detection" in the datasheet, with no further elaboration. The reference design simply pulls up AUXDCN to 3.3V and pulls down AUXDCP to GND through 100k resistors, with no further connection, and thus this design does the same.

---
### PDB
> *Pin: PDB (4)*

Active low power down pin for the PS176. It is pulled up to 3.3V by a 10k resistor and connected to RP2350B_2 GPIO to allow the user to disable the PS176 in software to ensure lower power consumption, though the PS176 only consumes 70uA of current in Auto Power Down mode. In the reference design, it is not connected to an MCU.

---
### Additional Pins
> *Pins: REXT (36), RESETB (35), GPIO3 (10)

- REXT: Pulled down to GND (per datasheet) by 5.1k resistor with no further connection.
- RESETB: Active low reset, pulled up to 3.3V by 10k resistor to prevent reset with 1uF bypass capacitor to avoid noise causing PS176 to reset. 
- GPIO3: Has an internal pull-up at ~80k, but reference design has it pulled *down* by a 4.7k resistor. The datasheet does not mention if this pin is particularly notable, and the reference design does not explain why it's pulled down, but the pull down resistor is kept regardless. Can be desoldered if necessary.

---
### Disconnected Pins
> *Pins: TESTMODEB (2), GPIO1 (5), GPIO4 (12), GPIO2 (27)*

- TESTMODEB: "Test mode control, NC for normal operation" per datasheet, hence the pin is left floating in the design.
- GPIO1, GPIO2, GPIO4: Has internal pull-ups at ~80k, and reference design floats these pins because they are not used, so they are floating in this design too.

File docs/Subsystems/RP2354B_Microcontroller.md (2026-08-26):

# RP2354B Microcontroller Subsystem

## Preamble
The LAZARUS-1 PCB implements three RP2354B MCUs to control pretty much all other components on the board. This includes: PWM fans, SATA ports (port enabling, fault detection, current sensing, and DSS pin enabling), power sequencing/LED control for the host laptop, SSD enabling, PS176 enabling, downstream USB 2.0 port fault detection, and programming for the USB7205C, TPS65987D, and TPS55288. Dedicated MCUs to control all of these components are used instead of GPIO expanders because:
1. Dedicated ADCs are needed to read the analog signals from the SATA eFuses for current monitoring (the RP2354B is chosen over the smaller RP2354A because it has 8 ADC channels exposed vs. 4, and 24 are needed in total). The LicheeRV Nano only has one exposed ADC channel, and so dedicated MCUs are needed.
2. Power sequencing ideally occurs on a bare metal system instead of an SBC for reliability purposes, thus requiring an MCU.
3. Base functionality of the entire system (other than IPKVM and temperature/current monitoring) should be available in absence of an SBC, in case a failure occurs on it. The USB7205C and TPS65987D (and by extension, the TPS55288) require programming over I2C because external flash chips are omitted in this design, and so MCUs are preferred for this purpose.
4. Since the RP2354B's can be implemented fairly minimally (requiring only a crystal oscillator and some decoupling capacitors), and so it does not take substantially more board space than a GPIO expander.

The RP2354B was specifically chosen for the following reasons:
1. It's fairly cheap ($1.62 USD per chip on LCSC).
2. It's easy to program because it's a Raspberry Pi product
3. It has an integrated 2MB flash, omitting the need for an external SPI flash chip.
4. It has enough GPIO to fulfill the needs of this PCB.
5. It has a relatively high number of ADC channels, which are needed for current monitoring through the SATA eFuses.

This design is largely based on the official [RP2350 Hardware Design Guide](https://pip-assets.raspberrypi.com/categories/1214-rp2350/documents/RP-008280-DS-1-hardware-design-with-rp2350.pdf), which implements a minimal design example of the RP2350 (which is pin compatible with the RP2354). However, the design removes the physical RESET button, replacing it with a single pad that can be shorted to GND with a wire if needed. Moreover, the USB port, along with the BOOTSEL button, are replaced with a 3-pin header for SWD; this will require an external SWD programmer, but provides a substantial PCB space savings. Additionally, a single UART TX/RX lane, along with GND, are exposed as pads on the PCB. Other than those modifications (and the lack of an external SPI flash, since the RP2354 has an internal flash), the design is very similar to the linked design guide.

## Description
The RP2354B is a microcontroller from Raspberry Pi that is pin compatible with the RP2350. It features 48 GPIO pins, 8 of which are connected to its 8 ADCs. In the LAZARUS-1 Backplane PCB, it is used to control the PWM fans, SATA ports (port enabling, fault detection, current sensing, and DSS pin enabling), power sequencing/LED control for the host laptop, SSD enabling, PS176 enabling, downstream USB 2.0 port fault detection, and programming for the USB7205C, TPS65987D, and TPS55288.

## Revision Progress

| Stages | RP2354B |
| --- | :---: |
| Initial Design | ✅ 2026-07-12 |
| Basic Function Review/Documentation  | ✅ 2026-07-31 |
| Extended Design Review/Documentation | |
| Initial PCB layout | |

## Design
The design of this subsystem is largely based on the official [RP2350 Hardware Design Guide](https://pip-assets.raspberrypi.com/categories/1214-rp2350/documents/RP-008280-DS-1-hardware-design-with-rp2350.pdf).

---
### USB, SWDIO, and UART
The RP2350 ordinarily uses USB for programming or booting. However, to save valuable PCB space, the USB connector has been removed, along with the BOOTSEL button that enables USB booting. Instead, the SWDIO pins (which are exposed to a 3-pin header) are used for programming, which requires a SWD programmer.

As a backup, UART is also exposed on GPIO28 and GPIO29 (UART0 TX and RX) as pads on the PCB.

---
### Input Power Supply
The official design guide supplies power to the RP2350 using a Micro USB connector, with an LDO to step down the voltage from +5V to +3.3V. However, since the LAZARUS-1 PCB has a dedicated +3.3V rail from its ATX PSU, +3.3V is simply siphoned from that rail to the RP2354B.

It's worth noting that the *source* of the +3.3V varies depending on which RP2354B is examined. Specifically, RP2354B_1 and RP2354B_2 source their +3.3V power from the regular +3V3DC pins of the ATX PSU connector, whereas RP2354B_0 sources its +3.3V power from the +5VSB (a +5V rail that is on even when the PS_ON# has not been grounded). This is because RP2354B_0 is responsible for power sequencing and hence must be on at all times.

Following the design guide, 100nF decoupling capacitors are placed on each +3.3V input pin. The design guide mentions that some decoupling capacitors are necessarily shared due to routing complexity (they use a 2 layer board), but this design can avoid those complexities by using a 4 or 6 layer PCB and by routing components on the bottom side of the PCB (if needed). These decoupling capacitors must be placed as close as possible to the input power pins.

---
### Internal Regulator
> *Pins: VREG_VIN (64), VREG_LX (63), VREG_FB (65), VREG_PGND (62), VREG_AVDD (61)*

The RP2354B has an internal switching regulator that steps down the +3.3V supplied by the PSU to +1.1V, which is used for DVDD. Following the design guide:
- a 4.7uF decoupling capacitor is placed on VREG_AVDD, with a 33Ω resistor between it and +3.3V;
- VREG_VIN is directly connected to +3.3V;
- VREG_FB is directly connected to +1.1V with a 4.7uF decoupling capacitor;
- VREG_LX is connected to +1.1V through a 3.3uH inductor, and;
- VREG_PGND is connected to GND.

The 3.3uH inductor chosen for this design is similar to the one used in the design guide, with similar saturation current. lower DCR, and a slightly larger package.

Similar to the +3.3V rail, decoupling 100nF capacitors are included for each pin, with the exception of DVDD (pin 10), which has a 4.7uF decoupling capacitor in accordance with the design guide.

---
### SPI Flash Pins
> *Pins: QSPI_SD3 (70), QSPI_SCLK (71), QSPI_SD0 (72), QSPI_SD2 (73), QSPI_SD1 (74), QSPI_SS# (75)*

The RP2354B has an internal 2MB flash, and so an external SPI flash chip is not needed. Per the datasheet, the internal flash's pins are shorted to the same QSPI output pins of the QFN package, and so the same functionalities may be used with the QSPI pins as the RP2350. This includes using QSPI_SS as a BOOTSEL button, though this is not included in this design because USB is omitted. However, additional resistors As such, all of the QSPI pins are left floating. However, the QSPI_IOVDD pin is still kept at +3.3V.

---
### Crystal Oscillator
> *Pins: XIN (30), XOUT (31)*

The crystal oscillator configuration used in the design guide is very specific and likely only works with that specific oscillator. Unfortunately, that oscillator is rather expensive to purchase. So, this design replaces it with an oscillator that has the exact same load capacitance and frequency stability, but 10Ω higher ESR. This is not *too* far off from the design guide, so the same 1kΩ resistor is used, but it can be replaced if necessary. Otherwise, the 15pF capacitors are the same.

---
### I2C Pins
> *Pins: GPIO0/SDA0 (77), GPIO1/SCL0 (78), GPIO38/SDA1 (47), GPIO39/SCL1 (48), GPIO37/IRQ1 (46)*

Both I2C0 and I2C1 channels are used in this design. I2C0 is a slave interface that is connected to the LicheeRV Nano's I2C1 (master) channel, and this is true for all three RP2354B's used in this design. This allows the LicheeRV Nano to request telemetry data (or send control signals) to the RP2350B. Since there are multiple devices using this interface, the 10kΩ pull up resistors are included in the LicheeRV Nano schematic page, and no where else.

The I2C1 channel of the RP2354B is a master interface to allow the RP2354B to program any connected devices, namely the TPS65987D and the USB7205C. On the I2C1 channel, 10kΩ pull up resistors are included for the SDA, SCL, and IRQ traces, which is fine since there is only ever one device on each channel. Note that RP2354B_2 does not have any device connected to its I2C1 channel, and so those pins are left floating.

---
### ADC Pins
> *Pins: GPIO40 to GPIO47*

The RP2354B has eight ADC channels. In this design, each ADC channel reads the analog current monitor reading from the eFuse of either the 5V or 12V rail of each SATA port. Since there are 12 SATA ports, and two voltage rails each, a total of 24 ADC channels are needed, hence the use of three RP2354Bs. Therefore, all three RP2354Bs have each of their ADCs occupied by one of the eFuse current monitor outputs. Below is the table detailing which voltage rail and SATA port number correspond to the ADCs of each RP2354B.

| RP2354B Number | Pin name | Voltage Rail Monitored | SATA Port Number |
| --- | --- | --- | --- |
| 0 | GPIO40/ADC0 | 12V | 0 |
| 0 | GPIO41/ADC1 | 5V | 0 |
| 0 | GPIO42/ADC2 | 12V | 1 |
| 0 | GPIO43/ADC3 | 5V | 1 |
| 0 | GPIO44/ADC4 | 12V | 2 |
| 0 | GPIO45/ADC5 | 5V | 2 |
| 0 | GPIO46/ADC6 | 12V | 3 |
| 0 | GPIO47/ADC7 | 5V | 3 |
| 1 | GPIO40/ADC0 | 12V | 4 |
| 1 | GPIO41/ADC1 | 5V | 4 |
| 1 | GPIO42/ADC2 | 12V | 5 |
| 1 | GPIO43/ADC3 | 5V | 5 |
| 1 | GPIO44/ADC4 | 12V | 6 |
| 1 | GPIO45/ADC5 | 5V | 6 |
| 1 | GPIO46/ADC6 | 12V | 7 |
| 1 | GPIO47/ADC7 | 5V | 7 |
| 2 | GPIO40/ADC0 | 12V | 8 |
| 2 | GPIO41/ADC1 | 5V | 8 |
| 2 | GPIO42/ADC2 | 12V | 9 |
| 2 | GPIO43/ADC3 | 5V | 9 |
| 2 | GPIO44/ADC4 | 12V | 10 |
| 2 | GPIO45/ADC5 | 5V | 10 |
| 2 | GPIO46/ADC6 | 12V | 11 |
| 2 | GPIO47/ADC7 | 5V | 11 |

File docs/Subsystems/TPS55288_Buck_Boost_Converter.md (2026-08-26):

# TPS55288 Buck Boost Converter Subsystem
## Preamble
The TPS65987D controls an external buck/boost converter to provide up to 5A @ 20V to the VBUS rail of the USB-C connector. In the TI's reference TPS65987D designs, an LM3489 buck controller is paired with a series of MOSFETs that adjust the resistance values to provide this power; however, this uses a significant amount of PCB space. A solution who's output voltage is controlled over I2C uses far fewer external components.

The TPS55288 was chosen mainly because it can be controlled over I2C, and has a relatively detailed official software configuration guide published by TI themselves that integrates the TPS55288 with the TPS65987D. This makes setup easier, while also reserving PCB space for other subsystems.

The TPS55288 also achieves mid-to-high 90% efficiencies at all output voltages, which is ideal for a home server application, where power usage is of high concern. It is by far the most efficient buck converter used on the entire board.

## Description
The TPS55288 is a four-switch buck-boost converter that can output 0.8V to 22V from a 2.7V to 36V supply input with up to 97% efficiency (with 12V input to 20V 3A output). It supports up to 6.35A output in 50mV increments. The output voltage can be configured over I2C, allowing the TPS55288 to be used for USB-C PD applications. It comes in a tiny 4x3.5mm QFN package, and is readily available on LCSC for only $2.79 USD.

## Revision Progress

| Stages | TPS55288 |
| --- | :---: |
| Initial Design | ✅ 2026-07-06 |
| Basic Function Review/Documentation  | ✅ 2026-08-16 |
| Extended Design Review/Documentation | |
| Initial PCB layout | |
## Relevant Docs
- [USB-C PD Source with TPS65987D and TPS55288](https://www.ti.com/lit/ab/slvaeq7/slvaeq7.pdf?ts=1786370541378)
- [TPS55288 Datasheet](https://www.ti.com/lit/ds/symlink/tps55288.pdf)
- [TPS55288 EVM](https://www.ti.com/lit/ug/slvubo4b/slvubo4b.pdf)
# Design
This design is largely based on the TPS55288 EVM and datasheet.

### Power path
The overall power path of the TPS65987D and TPS55288 is as follows:
- Setting power profile: TPS65987D I2C master -> TPS55288 I2C slave
- Power path: `+12V` ATX PSU rail -> TPS55288 `V_IN` pin -> TPS55288 `V_OUT` pin -> TPS65987D `PP_HV1` and `PP_HV2` pins -> TPS65987D VBUS pin -> VBUS pin of USB-C port

In essence, the TPS65987D communicates to the TPS55288 over I2C to control its voltage output, and then the TPS55288 converts the 12V from the ATX PSU rail to whatever voltage is needed for USB-C PD, and outputs that back to the TPS65987D's internal power path, which is connected to the VBUS pin of the UBS-C port.

### Gate Drivers
> *Pins: DR1L (1), DR1H (2)*

Buck and boost converters both operate using switches that repeatedly open and close a circuit to step up the current while decreasing the voltage (buck) or step down the current while increasing the voltage (boost). The switches that are used for these converters are typically MOSFETs, and to prevent the current from flowing back into the inductor during the OFF cycles (for buck), a diode is typically used for basic buck designs. However, the TPS55288 replaces this with another MOSFET, leading to a four-switch design split into two internal MOSFETs for the boost side, and two external N-MOSFETs for the buck side. This negates the voltage drop across the diode, leading to greater efficiency (97% peak), which is highly important for this subsystem given its high current nature.

The two external MOSFETs on the buck side are labelled as either "high-side" or "low-side"; high-side refers to the MOSFET that has its drain connected to the input voltage, whereas low-side refers to the MOSFET that has its source connected to ground. The high-side's source is connected to the low-side's drain, and both gates are controlled by DR1H and DR1L respectively. During buck operation, DR1L and DR1H are repeatedly switched on and off (never both at the same time?) to achieve a lowered voltage.

In the datasheet, DR1L and DR1H are directly connected to their respective MOSFET gates. However, in the EVM, a 1Ω series resistor is placed between DR1L/DR1H and the MOSFET gates. This is likely for EMI reasons, and so it is replicated in this design.

SW1 is also connected to the high-side source/low-side drain; this is so that the current sense inductor (and thereby the boost side) can still receive the input voltage during boost mode.

>[!WARNING] Note: the EVM uses the `Infineon IPZ40N04S5L4R8ATMA1` MOSFET, whereas this design uses the `HUASHUO HSBB4056`.
>This needs to be verified still; the specs seem to line up and it's the #1 listed alternative on LCSC, but further verification is still needed due to the importance and sensitivity of this part of the subsystem.
### Output Current Limit Pin
> *Pin: ISP (12), ISN (13)*

The TPS55288 uses the ISP and ISN pins to sense current through a current sense resistor; when the voltage across the current sense resistor exceeds the rated maximum (specified in a register in software), a slow constant current control loop between ISP and ISN regulates the voltage between the two pins, thus clamping the current. The value of the current sense resistor determines the current at which overcurrent protection is tripped, and this value is calculated by: `R_SNS = V_SNS / I_OUT_LIM`

Per the datasheet, `V_SNS` is 50mV by default, and so for `I_OUT_LIM` to be 5A, `R_SNS` must be 10mΩ. This ensures that the current does not surpass the 5A PD specification. Tolerances in the current sense resistor could lead to the actual current being lower than 5A, but this is an average inductor current limit, and so transient spikes may not necessarily trip the OCP. Furthermore, the downstream TPS65987D is limited to 5A per its datasheet, and so a lower current sense resistor value is not used; slightly lower sustained current than 5A is still acceptable for most applications.

The datasheet also mentions that the current sense resistor mentioned should be rated for the power dissipation expected across it. In this case, with an inductor voltage of 50mV and a max current of 5A, the maximum power dissipated is 250mW. The resistor chosen is rated for 1W, and is therefore well within specification.

An additional 100nF capacitor is placed between the two pins to filter noise.

### V_IN Pin
> *Pin: VIN (3)*

The V_IN pin takes in an input voltage between 2.7V and 36V; however, for this application, VIN=12V is used to match the ATX PSU main supply rail. Substantial filtering is applied to this pin using bypass capacitors; in accordance with the EVM, a 1uF capacitor is placed close to the pin itself, with an additional 1uF, 2 x 10uF, and 68uF placed nearby.

All capacitors chosen on this line are rated for 25V or higher.

### EN/UVLO Pin
> *Pin: EN/UVLO (4)*

The EN/UVLO pin enables the function of the TPS55288; logic high enables the device, whereas logic low disables it and turns it into shutdown mode. The pin (enable) reads high at 1.15V, but the UVLO (minimum voltage before it shuts down the device) is 1.20V to 1.26V, with 1.23V typical. This is achieved through a resistor divider between V_IN and GND; when V_IN reaches undervoltage, the resistor divider should trigger this pin and disable the device.

To ensure that the EN/UVLO pin is not triggered prematurely (i.e., within tolerance of +12V ATX spec), the absolute worst-case scenario in which voltage output is still allowed is considered. The +12V ATX rail has a ±5% tolerance per the ATX v2.2 specification, which means that the worst case allowable voltage on the rail, for the purposes of this task, is +11.4V. Moreover, UVLO's maximum voltage is considered part of the worst case scenario, and so UVLO = 1.26V is considered as well. Hence, a resistor divider between 11.4V and GND that achieves an intermediary 1.26V is considered.

When considering the resistor tolerances, the effective worst-case resistor tolerance would be if the resistor between V_IN and EN/UVLO was at its highest value, and the resistor between EN/UVLO and GND was at its lowest value. Thus, the worst-case resistor divider value ratio should be `1.26 / 11.4V = 0.1105`. By choosing a top resistor of 220kΩ±1% and a bottom resistor of 28kΩ±1%, the lowest possible resistor divider ratio becomes 1.264, which is above the maximum UVLO voltage of 1.26V.

These calculations are very important, as the TPS55288 shutting down in high current scenarios is catastrophic to the operation of the LAZARUS-1 server; for example, when performing a critical render or other important computationally intensive operation on the laptop connected to the device, any drop out in power would be highly detrimental. To further aid this, and in accordance with the EVM, a 100nF capacitor is added between EN/UVLO and GND to filter noise.

### I2C Pins
>*Pins: SCL (5), SDA (6)*

The I2C channel of the TPS55288 connects directly to the TPS65987D, with 10kΩ pull up resistors on both SCL and SDA; the pull up resistance is very straightforward to choose because there are no other devices on this channel. This is an I2C slave interface on the TPS55288 side, which allows the TPS65987D to set the output voltage of the TPS55288, along with configuring any of its internal registers.

### MODE Pin: I2C Address Selection and Operating Mode at Light Load
> *Pin: MODE (15)*

Per the datasheet, the MODE pin serves two functions, based on the resistor value between it and VCC (either internal or external). Internal VCC is provided by an internal regulator to the VCC pin (19), and external VCC is +5V provided by the +5V ATX PSU rail. However, to minimize power dissipation, +5V is applied to the VCC pin of the TPS55288 in this application, and so only external VCC can be used for the MODE pin.

The first function of the MODE pin is to select the slave address of the TPS55288. The exact address chosen does not really matter for this application, since the TPS55288 is the only device on the TPS65987D's I2C1 interface; it matters only for programming the TPS65987D, where the exact address that the TPS65987D must target on startup is important to pinpoint.

The second function of the MODE pin is to select if the TPS55288 operates in PFM (Pulse Frequency Modulation) or PWM (Pulse Width Modulation). Per the datasheet, PFM decreases the switching frequency to decrease switching loss and achieve much higher low-current efficiency (~90% at 12V input with 0.01A @ 20V output vs. ~30%), with the tradeoff of less-predictable EMI/noise. On the other hand, PWM (or rather, forced-PWM) keeps the switching frequency constant during light loads, which leads to no low-frequency noise, but worse efficiency. For this application, PFM is selected for its higher efficiency; low-frequency noise is not as detrimental to this system, as are not really any particularly noise-sensitive parts (e.g. RF, audio, etc.) on this PCB.

To set PFM, the MODE pin is floated in this design. This is chosen over the other options in the datasheet, which all use a pull up or pull down resistor, as this still achieves PFM while using one less component.

That said, the actual mode used for this system is decided entirely based on the value written to the `6h` register, after the system has received programming over I2C. 

### DITH/SYNC Pin
> *Pin: DITH/SYNC (7)*

The TPS55288 operates at a fixed PWM frequency, and as a result, has significant EMI concentrated at that frequency (known as narrowband). This can pose challenges for testing and certification (which is not really all that important for this application), but also just makes the voltage rails and surrounding areas on the PCB noisier at the specific frequency that the TPS55288 operates at. Aside from specific layout considerations to reduce noise, bypass filtering, snubbers, and shielding, dithering — which wobbles the switching frequency over time to spread out EMI over a wider band (i.e., broadband) — can help handle large EMI spikes.

The TPS55288 enables and adjusts dithering through its DITH/SYNC pin. By adding a capacitor between this pin and ground, the TPS55288 can charge and discharge the capacitor to create a triangular voltage waveform that modulates the TPS55288's fixed PWM frequency by ±7%. The capacitance of the dithering can be set by the value of the capacitor, the equation for which is provided by:
```
C_DITH = (2.8 × R_FSW × F_MOD)^-1 [F]
```

...where `R_FSW` is the resistor value at the FSW pin, and `F_MOD` is the desired modulation frequency.

For the purposes of this application, a 10nF capacitor is used, which matches the EVM. Matching the EVM here is helpful because it permits replicating the same COMP resistor/capacitor network.

The DITH/SYNC pin also disables dithering if the voltage at that pin is below 0.4V or above 1.2V, or when an external synchronous clock is used (which it isn't, in this application). If dithering must be disabled, the 100nF capacitor can simply be shorted to GND to achieve this.

### FSW Pin
> *Pin: FSW (8)*

The FSW pin sets the frequency at which the TPS55288 switches at in PWM mode. The value of the resistor between this pin and GND dictates this frequency, and is calculated using the following formula:
```
f_FSW = 1000 / (0.05 × R_FSW + 20) [MHz]
```

...where `R_FSW` is the resistor value, and `f_FSW` is the frequency that results from it. The EVM and datasheet's example circuit both use a 49.9kΩ resistor, and so that is what is used in this application. This results in a 400 kHz switching frequency.

### PGND and AGND
> *Pins: PGND (9, 24), AGND (10)*

PGND is Power Ground, and AGND is Analog Ground. The tl;dr is that PGND and AGND should be separated except at the terminal of the capacitor at VCC, to prevent the noise from the MOSFETs switching and parasitic inductance to affect the sensitive analog pins of the TPS55288.

### VOUT Bypass Capacitors
> *Pin: VOUT (11)*

The VOUT pin is, as the name suggests, the voltage output of the TPS55288. It is connected directly to the 10mΩ sense resistor and the ISP pin for current sensing, which then connects to the VBUS pin of the USB-C connector to power the laptop. This pin has several bypass capacitors attached to it, which must all be rated for 25V or higher (ideally >35V), as the voltage can be as high as 20V sustained at this pin.

The EVM has more capacitors on this pin than the datasheet, and the LAZARUS-1 PCB follows the EVM (for this specific pin). So, 4x10uF, 1x1uF, 1x100nF,  and 1x220uF capacitors are placed between this pin and PGND, placed close to the pin itself. Note that the 220uF capacitor used here is an aluminum electrolytic capacitor, which has polarity; the positive end *must* be connected to VOUT for proper functionality.

Additionally, in accordance with the EVM, a 1uF bypass capacitor is placed immediately following the current sense resistor.

### SWx and BOOTx Pins
> *Pins: SW1 (23), SW2 (21, 25), BOOT1 (22), BOOT2 (20)*

Per the datasheet, the SW1 is the switching node of the buck side of the TPS55288, and it connects to the drain of the external low-side power MOSFET, as well as the source of the external high-side power MOSFET. On the other hand, SW2 is the switching node of the boost side of the TPS55288, which means that it connects to the drain of the *internal* low-side power MOSFET and the source of the *internal* high-side power MOSFET. For layout purposes, only SW1 has to be routed to anything else; SW2 only connects to an inductor between it and SW1. 

An inductor is placed between SW1 and SW2. The EVM and datasheet both recommend the `XAL1010-472ME` 4.7uH inductor, but this inductor is far too expensive and is not in stock at LCSC. The datasheet also lists two other alternatives, one of which is the Sumida `125CDMCCDS-4R7MC`. This is available on LCSC, and has an alternative part (the XR `XR XR1265-4R7M`) that is substantially cheaper and has lower DCR, higher I_SAT, and is otherwise the exact same. That is the inductor used for this application.

BOOT1 and BOOT2 are the power supply pins for the high-side gate driver on the buck and boost sides respectively. A 100nF capacitor connects this pin to SW1 (for BOOT1) and SW2 (for BOOT2).

### COMP Pin
> *Pin: COMP (18)*

The COMP pin, per the datasheet, is the output of the internal voltage amplifier. Unfortunately, the datasheet does not comprehensively detail what that is, but it does provide formulae for calculating the values of the resistor/capacitor network attached to this pin. However, since this application uses the same general configuration for everything (output voltage/current, switching frequency, dithering frequency), the same resistor/capacitor network can be used.
> [!WARNING]
> This needs to be verified...

### ILIM Pin
> *Pin: ILIM (17)*

The TPS55288 supports average current limiting through the external 4.7uH inductor; this is performed through the ISP and ISN pins, which sense the average voltage across the inductor and calculate the current. However, momentary spikes in current that are far above the average current occur during switching, and the TPS55288 also supports sensing this current. This peak current is set using the ILIM pin. Per the datasheet, a 20kΩ pull down resistor is recommended here (which is also used in the EVM), and hence that is what is implemented in this design.

### CDC Pin
> *Pin: CDC (16)*

On the CDC pin, the TPS55288 outputs a voltage equal to `20 × (V_ISP - V_ISN)`, which can be used for current monitoring. In this application, this pin is connected to the LicheeRV Nano's ADC pin to perform current monitoring, which is preferred over using a PAC1954 because the PAC1954 presents a (small) amount of loss across its own current sense resistor. Note that because of the `20×` multiplication of the voltage, a separate operational amplifier circuit (like what the ADCs use for the 12V/5V rails of each SATA port in this design) is not needed; the voltage is high enough that the voltage sensed by the LicheeRV Nano is sufficiently accurate.

In addition to current sensing, this pin can be used for droop compensation. The USB-C cable that is connected to this PCB presents some amount of resistance, which leads to the actual voltage presented to the connected laptop being slightly lower than at the output of the TPS55288. To compensate for this, the output voltage can be increased slightly through droop compensation, which occurs through the pull down resistors on the CDC and FB/INT pins. This is for *external* compensation; however, *internal* compensation, which does not require resistors on either of these pins, can be used instead, and uses an internal voltage divider to achieve the same thing. Internal compensation is controlled by writing the intended voltage compensation into the CDC[2:0] bits in register `05h` of the TPS55288. This is what is used in the LAZARUS-1 PCB, as it requires fewer resisters. As a result, the CDC pin is not connected to a pull down resistor, and is instead only connected to 

### FB/INT Pin
> *Pin: FB/INT (14)*

In external compensation mode, the FB/INT pin must be wired to the middle of a voltage divider (through a single external resistor) to configure droop compensation. However, in internal mode (which is what is used in this design), the FB/INT pin just acts as a fault indicator. It is thus pulled up to 3.3V by a 10kΩ resistor, and is connected to an RP2354B for fault detection.

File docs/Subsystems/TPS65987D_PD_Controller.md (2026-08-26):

# TPS65987D USB-C PD 3.0 Controller
## Preamble
The USB-C PD controller chosen for the LAZARUS-1 PCB is actually labelled as Not Recommended for New Designs (NRND), and has relatively low stock on LCSC. However, it was still chosen for the following reasons:
1. As of the time of writing, it is the only *readily available* PD controller that supports 100W PD, DRP, DisplayPort alt-mode, and an integrated power path from TI.
2. As of the time of writing, it is also the only *well documented* PD controller that supports these features, from any company.
3. It can still be purchased for relatively cheap on LCSC, albeit with low stock. Get them while you can, I guess.

Point number 1 relies heavily on the "readily available" part because I started this project literally *just as* TI released the TPS26743E-Q1 (single port) and the TPS26744E-Q1 (dual port) PD controllers, which support up to 240W EPR and DisplayPort. However, they don't have an integrated power path, so they would still require a bunch of extra MOSFETs that the TPS65987D would not need. As of the time of writing, there is no direct replacement for the TPS65987D from TI.

From other vendors (specifically VIA Labs), there are comparable alternatives to the TPS65987D (VL103/VL105, some chips from Infineon). However, they are much less documented (no official reference designs, poor/unofficial documentation) and harder to procure (out of stock on LCSC). And they're not even cheaper really, so I didn't see much of a point in going with those over the TPS65987D.

All that said, the only main drawback to the TPS65987D is its NRND status; it fulfills all the requirements of this design, and plays nicely with the TUSB1064 and TPS55288.

## Description
The TPS65987D is a stand-alone USB Type-C PD controller with DisplayPort alt-mode support that detects cable orientation and negotiates PD through the USB-C CC pins. It communicates a power profile over I2C to an external boost/buck converter (TPS55288) and feeds power through its integrated power path. It supports 20V 5A PD as a USB-C PD source.

## Revision Progress

| Stages | TPS65987D |
| --- | :---: |
| Initial Design | ✅ 2026-07-06 |
| Basic Function Review/Documentation  | ✅ 2026-08-07 |
| Extended Design Review/Documentation | |
| Initial PCB layout | |

## Relevant Docs
- [TPS65987D SPI Less Host Programming Over I2C](https://e2e.ti.com/cfs-file/__key/communityserver-discussions-components-files/196/SPI_5F00_Less_5F00_EC_5F00_Based_5F00_Host_5F00_Programming_5F00_Over_5F00_I2C_5F0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)
- [TPS65987D Hardware Design Guide](https://www.ti.com/lit/an/slva888c/slva888c.pdf?ts=1785751478359)
- [TPS65987D Datasheet](https://www.ti.com/lit/ds/symlink/tps55288.pdf?ts=1785754959009)
- [TPS65987D PD Source Design](https://www.ti.com/tool/TIDA-050012)
## Design

### Power Path
The TPS65987D has an integrated power path, which means that the 20V 5A (or lower voltage/current) originating from the TPS55288 buck/boost converter can pass through the TPS65987D internally first before reaching the USB-C connector's VBUS pins. Alternatively, an external power path that bypasses the buck/boost converter can be used, which allows 20V to be delivered to the USB-C cable with minimal loss. However, this is only the case if the input supply is 20V (e.g., the TIDA-050012 Power Duo Source reference design), which it is not. So, the external power path is not used. The full power path is therefore as follows:

12V ATX PSU rail -> TPS55288 VIN -> TPS55288 VOUT -> TPS65987D PP_HV -> TPS65987D VBUS -> USB-C VBUS pin

Additionally, PP_HV1 and PP_HV2 are two technically separate power paths. However, in a self-powered dock design such as the LAZARUS-1 PCB, two separate paths are not necessary, so both are used for the same (up to) 20V 5A power path. In accordance with the design guide for systems configured as a source, each PP_HV path has a 10uF decoupling capacitor.

---
### VBUS Protection
Since the VBUS pin of the TPS65987D goes directly to the USB-C connector, which is prone to shorts or voltage surges whenever the USB-C cable is disconnected.

In accordance with the design guide, a TVS2200 TVS diode is placed between GND and VBUS, close to the VBUS pin of the USB-C connector. Furthermore, a 10kΩ resistor paired with a white LED are placed between VBUS and GND to indicate power being transferred. VBUS will vary depending on the voltage required by the system, so the LED will get brighter with higher voltage. However, even at 20V, the LED will not exceed ~2mA of current, which ensures that it won't experience accelerated burn out.

---
### Input Power Supply
> *Pin: VIN_3V3 (5)*

The TPS65987D itself needs its own +3.3V supply to function. In this design, this is sourced from the +3.3V rail of the ATX PSU (and not the +3.3VSB rail, since this chip does not need to be on when the system is shut off). Per the design guidelines, a 10uF decoupling capacitor is placed on this rail.

---
### Internal LDOs
> *Pins: LDO_3V3 (9), LDO_1V8 (35)*

These pins are internal LDO outputs. LDO_3V3 is intended for logic devices connected to the TPS65987D (such as an SPI flash chip or I2C pull up resistors), and LDO_1V8 powers internal digital circuitry. Per the design guide, a 4.7uF decoupling capacitor is placed close to the LDO_1V8 pin. Additionally, a 10uF decoupling capacitor is placed close to the LDO_3V3 pin, matching the EVM.

---
### SPI Flash Pins
> *Pins: SPI_PICO (36), SPI_POCI (37), SPI_CLK (38), SPI_CS (39)*

SPI Flash is not used in this design; instead, the TPS65987D is programmed over I2C by RP2354B_0. Per the datasheet, if unused, the SPI pins should be grounded, which is the configuration implemented in this design.

---
### Boot Configuration
> *Pin: ADCIN1 (6), SPI_POCI (37)*

ADCIN1 is connected to a resistor divider that sets the TPS65987D's boot configuration. Based on the resistor division value, along with the SPI_POCI configuration, the TPS65987D determines its default startup behaviour. This includes dead battery mode and regular device configurations.

Dead battery, in the case of the TPS65987D, simply refers to the state where the device with the PD controller has no power, but is connected to an active VBUS (e.g., laptop battery dead but VBUS providing power), and hence the VIN_3V3 rail is not yet active. This should never happen in this design, since it acts as the power source, not the sink. Moreover, whenever the TPS65987D boots up, there will always be power on the +3V3 rail. Thus, the dead battery mode configuration does not really matter for this application.

ADCIN1 also determines the boot configuration if an SPI flash device with configuration settings or an I2C interface is not found. The following are the configurations:

| Configuration | Description (from the datasheet) |
| --- | --- |
| Safe | Ports disabled, if powered from VBUS operates a legacy sink |
| Infinite Wait | Device infinitely waits in boot state for configuration information |
| Configuration 1 | DFP only (Internal Switch)<br>5 V at 3 A Source capability<br>TBT Alternate Modes not enabled<br>DisplayPort Alternate Mode not enabled (DFP_D, C/D/E) |
| Configuration 2 | UFP only (Internal Switch)<br>5 V at 0.9 - 3.0 A Sink capability<br>TBT Alternate Modes not supported<br>DisplayPort Alternate Modes not supported |
| Configuration 3 | UFP only (Internal Switch)<br>5-20 V at 0.9 - 3.0 A Sink capability<br>TBT Alternate Modes not supported<br>DisplayPort Alternate Modes not supported |
| Configuration 4 | UFP only (External Switch)<br>5 V at 0.9-3.0 A Sink capability<br>5 V at 3.0 A Source capability<br>TBT Alternate Modes not supported<br>DisplayPort Alternate Modes not supported |
| Configuration 5 | UFP only (External Switch))<br>5-20 V at 0.9-3.0 A Sink capability<br>5 V at 3.0 A Source capability<br>TBT Alternate Modes not supported<br>DisplayPort Alternate Modes not supported |

In an ideal case, this configuration never comes into action, because the RP2354B_0 *should* be providing the correct configuration over I2C. Nevertheless, if this doesn't happen, then the device should still act as a *source*, and not as a *sink*, since the PCB is not designed to take *in* power from VBUS. The only option in this table that supports that is Configuration 1, and thus that is chosen for this design.

> Note: technically Infinite Wait is still "safe", but it doesn't really bring any benefit over Config 1, since it just makes the TPS65987D do nothing.

The only boot mode pin strapping listed in the datasheet that supports Configuration 1 has dead battery mode set to `BP_NoResponse`, which states that the device does nothing unitl VIN_3V3 is present (i.e., the chip receives power, which it always should). Per the datasheet, this configuration requires:
- SPI_POCI grounded
- Resistor divider between 0.10 and 0.18

The safest resistor divider value is therefore 0.14, and R1=120kΩ, R2=20kΩ results in DIV=0.143, which is pretty close.
> Note: The datasheet and design guide both mention that tolerances of 1% are required, but the R2 selected has a 5% tolerance. This is likely still fine because the DIV still remains within the correct range with 5% tolerance.

---
### I2C Address
> *Pin: ADCIN2 (10)*

A resistor divider on ADCIN2 determines the I2C address of the TPS65987D. However, since each connected device on I2C is the only device on its bus, the I2C address does not really matter. Hence, the default address is chosen, which is `000b`. This requires a DIV range of 0.00 to 0.18, which can easily be achieved through a simple 100kΩ pull down resistor, as recommended by the design guide.

---
### Reset Pin
> *Pin: HRESET (44)*

The TPS65987D can be reset by pulling the HRESET pin high. This doesn't really need to be done, but just in case, a 0Ω resistor pull down is added. If reset functionality is ever needed, it can be replaced with a 100kΩ resistor, and the pin can be manually driven high.

---
### USB-C Configuration Channel Pins
> *Pins: C_CC1 (24), C_CC2 (26)*

The CC pins of the USB-C connector connect to the corresponding CC pins of the TPS65987D to allow the TPS65987D to negotiate and communicate cable orientation, device roles, and power/data modes with the connected laptop. Depending on the orientation, one of the CC pins gets converted to a VCONN pin, which provides 5V at up to 0.6A to the electronics internal to the connected cable if needed (e.g. for a Thunderbolt cable). This is a high speed connection, and decoupling capacitance is needed to ensure that it functions properly, Per the datasheet, the total capacitance on the CC lines needs to be 300pF, but there already exists ~100pF receiver capacitance. So, in accordance with the typical application schematic (and the EVM), both pins get a 220pF decoupling capacitor. This capacitor must be placed as close to the C_CC pins on the TPS65987D as possible.

---
### PP_Cable
> *Pin: PP_Cable (25)*

The PP_Cable pin on the TPS65987D is used as a power input, which is then fed to the VCONN output to power electronics within a connected USB-C cable (e.g., Thunderbolt controller). Prior to sending power through this pin to VCONN, the TPS65987D monitors the voltage; if it exceeds the safe voltage for that pin, it does not connect VCONN to PP_Cable. Otherwise, it does. The PP_Cable pin gets a 22uF decoupling capacitor in accordance with the datasheet and EVM, placed as close as possible to the PP_Cable pin.

---
### Battery Charger Detection and Advertisement
> *Pins: C_USB_P (50), C_USB_N (53)*

The TPS65987D supports BC1.2, which is a charging specification that allows up to 1.5A at 5V to be supplied to a connected device. Most laptops do not support this standard, as it is far too low power for most devices; it is primarily used in handheld devices. For this functionality to exist in this design, the USB 2.0 lanes of the USB-C connector must be routed to the TPS65987D to perform negotiation; however, the USB 2.0 lanes are already being routed to the USB7205C to be used for regular data transfer. So, BC1.2 is not supported in this design. 

Per the datasheet, when BC1.2 is not used, the C_USB pins are multiplexed as GPIO pins. The datasheet specifies that unused GPIO pins should be left floating, and thus the C_USB pins are left floating in this design.

---
### External Power Path
> *Pins: PP_EXT1 (48), PP_EXT2 (49)*

The TPS65987D supports an external power path, through two GPIO pins that control a series of MOSFETs that change the voltage that the boost/buck converter supplies. However, this power path is not used in this design, as a TPS55288 is used. The TPS55288 can be controlled entirely over I2C without GPIO control, so PP_EXT1 and PP_EXT2 are unused. In accordance with the datasheet, this pin is floated when unused.

---
### Drain Pins
The drain pins are connected to the drains of the internal power transistors for power path 1 and 2. They are *not* intended to be connected to ground, but *must* be connected to each other for thermal dissipation. There are two large drain pads on the QFN package, and this is to aid with thermal dissipation of the drain pins. All drain pins must be connected to their respective drain pads.

---
### HPD Pin
> *Pin: HPD (30)*

The HPD pin is used as a GPIO input pin that detects if a DisplayPort connection has been established, when the TPS65987D is used as a DisplayPort sink. It is connected to the PS176's DP_HPD output; whenever the PS176 signals a DisplayPort connection, the TPS65987D will read that through its HPD pin, and relay that signal to the connected laptop.

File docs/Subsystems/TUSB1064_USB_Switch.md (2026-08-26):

# TUSB1064 USB Switch Subsystem

# Description
The TUSB1064 is a USB-C redriving switch supporting up to 10Gbps data rates and DP 1.4. In other words, it connects to the TX and RX pins of the upstream USB-C port, and flips them depending on the orientation of the USB-C cable, as controlled by the TPS65987D PD controller over I2C. This ensures that the devices further down the USB data and DP paths do not need to account for orientation.

# Revision Progress

| Stages | TUSB1064 |
| --- | :---: |
| Initial Design | ✅ 2026-07-09 |
| Basic Function Review/Documentation  | ✅ 2026-07-22 |
| Extended Design Review/Documentation | |
| Initial PCB layout | |

# Design

### Power
The power circuitry for the TUSB1064 is pretty simple; it only uses 3.3V to power itself and for all the logic. So, the 3.3V ATX PSU rail is used, with the appropriate bypass capacitors (per the datasheet) included. One 100nF capacitor is included for each of the three VCC pins.

---
### TX Input Pins
The USB-C port routes transmit (TX) traces to the TUSB1064. Per the USB specification, the TX traces should have an AC coupling capacitor of 75nF to 265nF. 100nF is the recommended value on the TX traces, per the TUSB1064's hardware design checklist, but 220nF still falls within the specification, and is more commonly used on newer USB redriver and switch ICs (e.g., [TUSB1104](https://www.ti.com/lit/ds/symlink/tusb1104.pdf?ts=1784735179859)). So, 220nF AC coupling capacitors are placed on all TX traces in this design.
> Note that per the USB 3.2 specification, the polarity of the TX traces can be reversed in the PCB design without issue, as this is automatically corrected.

---
### RX Input Pins
The USB-C port routes receive (RX) traces to the TUSB1064. Per the USB specification, the RX traces do not *need* coupling capacitors, as they are supposed to already be there on the TX traces of the connected device. However, they can be optionally added on the RX side, per a [revision to the USB 3.1 Specification](https://e2e.ti.com/cfs-file/__key/communityserver-discussions-components-files/138/USB-3.1-ECN-Rx-AC-Coupling-Capacitor-Option.pdf). Since the tolerances are generally quite large on ceramic  capacitors (±20%), it's safer to use a 470nF capacitor over 330nF; if the TX side uses 100nF and the RX side uses 330nF, the net coupling capacitance is just 76.7nF, which is very close to the minimum.
> Note that per the USB 3.2 specification, the polarity of the RX traces can be reversed in the PCB design without issue, as this is automatically corrected.

---
### EQ Configuration Pins
> *Pins: CTL1 (23), EQ0 (11), EQ1 (14), SSEQ0 (38), SSEQ1 (3), DPEQ0 (35), DPEQ1 (2)*

The TUSB1064 can apply equalization to the signal traces to reverse attenuation and improve signal integrity. To configure the equalization applied, several pins can be used, *or* the TUSB1064 can be configured over I2C. In this design, the TUSB1064 uses I2C to communicate with the TPS65987D PD controller, and hence I2C is used to configure EQ. According to the datasheet:
> the configuration pin CTL1 and all of the equalization pins (EQ[1:0], SSEQ[1:0], and DPEQ[1:0]) can be left unconnected. If these pins are left unconnected, the TUSB1064 7-bit I2C slave address will be 0x12 because both DPEQ/A1 and SSEQ0/A0 will be at pin level "F". If a different I2C slave address is desired, DPEQ/A1 and SSEQ0/A0 pins should be set to a level which produces the desired I2C slave address.

Floating DPEQ0 and SSEQ0 is likely safe, however grounding both pins does not use significantly more board space since there is a dedicated ground plane, and grounding the pins may possibly be slightly safer, so they are grounded in this design. This leads to a slave I2C address of 0x88 (write) and 0x89 (read) for the TUSB1064. This will not interfere with any other I2C devices, since the TPS65987D's third I2C line is dedicated solely to the TUSB1064.

The rest of the EQ configuration pins are left floating, as they do not control anything if I2C is used for EQ.

---
### Hot Plug Detect Input (HPDIN) Pin
> *Pin: HPDIN (32)*

HPDIN is an input that is high when a DisplayPort sink (e.g., monitor) is connected. Per the datasheet, when HPDIN is low for ≥2ms, all DisplayPort lanes are disabled. This pin connects to the HPDIN pin of the TPS65987D and is controlled by the HPD output pin of the PS176.

A 100k pull down is added on the HPD trace to ensure that the default state of the HPD line is no monitor connected.

---
### DisplayPort Output Pins
DisplayPort consists of four differential data pairs, as well as a single AUX differential pair communication between devices. The DisplayPort specification requires 100nF AC coupling capacitors placed close to the transmitter side, and since they aren't included in the PS176 subsystem, they are included in this system.

---
### USB 3.2 Gen 2 Output Pins
> *Pins: SSRX+ (5), SSRX- (4), SSTX+ (8), SSTX- (7)*

The USB 3.2 specification requires AC coupling of 75nF to 265nF on the transmit side (TX); however, this is an embedded system without external ports, and the USB 3.2 output pins go directly to the USB7206C USB hub, and so the AC coupling capacitors in this design are also placed on the RX channel. Thus, each trace gets its own coupling capacitor. The capacitor used on these traces are 220nF capacitors, which fit comfortably in the specification. 100nF capacitors are used in the datasheet; however, 220nF is still safe, and more modern USB-C redrivers tend to recommend 220nF over 100nF.

---
### I2C Pins
> *Pins: CTL0/SDA (22), FLIP/SCL (21)*

I2C is used on the TUSB1064 to configure equalization and communicate USB-C cable orientation. In this system, the TUSB1064 is connected to the TPS65987D's third I2C bus, and is the only device on this bus. Since it is the only device on the bus, 10kΩ pull up resistors are used.

---
### SBU Pins
> Pins: SBU1 (24), SBU2 (25)

The SBU pins on the USB-C connector connect directly to the SBU pins of the TUSB1064. Per the USB-C specification, the SBU pins are used for alternate modes (such as DP alt mode, as in this system) or auxiliary communication (i.e., audio). In accordance with the datasheet, 2MΩ pull down resistors are attached to both SBU traces.

---
### AUX Pins
> *Pins: AUX+ (26), AUX- (27)*

These pins are bidirectional pins for DisplayPort, used to communicate device config and link management. As mandated by the TUSB1064 datasheet a 1MΩ pull down resistor is placed on AUX-, and a 1MΩ pull up resistor is placed on AUX+. Also mandated by the datasheet is a 100nF AC coupling capacitor, which is placed on both traces. On the side of the capacitors facing the PS176, 1kΩ pull up resistors are included in the PS176 subsystem.

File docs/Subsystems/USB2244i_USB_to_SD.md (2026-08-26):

# USB2244i USB to SD Card Subsystem
## Preamble
A simple, 480Mbps SD card reader is included on the LAZARUS-1 backplane PCB simply to allow easy "permanent" storage for things like ISOs, so that the laptop can boot into a live linux environment (or something else like Windows, if you're crazy) in case a new OS image needs to be flashed. It's intended to be exposed as a regular SD card reader to the OS, and so it's basically just another USB storage device. Hence, it's connected through the USB7205C hub to the laptop, and not to the LicheeRV Nano or RP2350's on the board. This unfortunately prevents the user from loading ISOs directly to the SD card when the host machine is off. However, the LicheeRV Nano itself also has an SD card slot, so this purpose is already fulfilled.

The USB2244i is the industrial version (higher rated temperature range) of the USB2244, which is a standard single chip USB 2.0 to SD card conversion IC. it supports many different flash media standards other than just SD, but for this purpose, only SD is used. This chip was mainly chosen because it is a Microchip IC, meaning it can be sourced for free from Microchip's free sample program for students.

## Description
The USB2244i is a dedicated, fully integrated single chip USB 2.0 to SD card controller, supporting (theoretical) 480Mbps SD card read/write speeds. It supports several flash media card specifications, but the one relevant to this application is SDHC/SDXC. It comes in a smaller 36-QFN package, as compared to more modern Microchip ICs like the USB2642, while consuming the same current when active. In suspend mode, it consumes only 350uA at +3.3V (~1mW), whereas it consumes 135mA at +3.3V (~0.5W) when active. It also supplies up to 200mA of current to the attached SD card through an integrated Power FET, allowing for better control of the SD card's power draw during suspend states.

## Revision Progress

| Stages | USB2244i |
| --- | :---: |
| Initial Design | ✅ 2026-07-12 |
| Basic Function Review/Documentation  | ✅ 2026-08-01 |
| Extended Design Review/Documentation | |
| Initial PCB layout | |

## Design

### Power
There are four power rails used by the USB2244i, as described in the table below.

| Power rail | Pin numbers | Description | Configuration |
| --- | --- | --- | --- |
| VDD33 | 6, 14, 22, 36 | Main 3.3 V power and regulator input | Each pin has its own 100nF decoupling capacitor, per the USB2244 design checklist. Connected to the ATX PSU 3.3V rail. |
| VDDA33 | 36 | Analog 3.3 V power input | Connected to the ATX PSU 3.3V rail, with a 100nF decoupling capacitor, per the USB2244 design checklist. |
| VDD18 | 13 | 1.8V core regulator output | Connected to a 1uF decoupling capacitor, per the datasheet. |
| VDD18PLL | 34 | 1.8V PLL regulator output | Connected to a 1uF decoupling capacitor, per the datasheet. |

> Note: VDD18 and VDD18PLL are not supposed to power external components, as they are intended to only power internal circuitry.

---
### USB 2.0 Pins
> *Pins: USB+ (2), USB- (3)*

Per the USB2244 Hardware Design Checklist, the USB2244i helpfully includes all the necessary terminations and resistors for USB on-chip, and so the USB 2.0 pins can be directly connected to the USB 2.0 pins of the USB7205C.

---
### SD Pins
> *Pins: SD_D0 (5), SD_D1 (1), SD_D2, (25), SD_D3 (23), SD_D4 (20), SD_D5 (10), SD_D6 (8), SD_D7 (7), SD_CLK (9), SD_CMD (11), SD_nCD (26)*

Because the USB2244i supports so many flash media card standards, there are more SD data pins than necessary for this application. SDXC only uses four data pins, and so SD_D4 to SD_D7 are left floating, which follows the USB2244 Hardware Design Checklist's recommendation. For SD_D0 to SD_D3, SD_CMD, and SD_CLK, series resistors are labelled as optional in the Hardware Design Checklist, and are thus not included in this design. They are therefore connected directly to their corresponding pins on the MicroSD card slot.

 SD_nCD (card detect) is connected directly to the corresponding pin on the MicroSD card slot, per the design guide. SD_WP (write protect) must be pulled down for MicroSD card functionality per the datasheet, but a specific pull down resistance is not specified. So, a standard 10kΩ resistor is used; if the value is incorrect, it can be swapped with another resistance value.

---
### Card Power Pins
> *Pin: CRD_PWR (21)*

The USB2244i can provide up to 200mA through the CRD_PWR pin to a connected MicroSD card. Routing power to the MicroSD through this pin is beneficial because the USB2244i has an internal power switch that disables power if more than 200mA is drawn. Per the design guide, a 4.7uF decoupling capacitor is added to this rail.

---
### Crystal Oscillator
> *Pins: XTAL1 (33), XTAL2 (32)*

The USB2244i requires a parallel resonant, fundamental mode 24 MHz reference clock to function, with a maximum tolerance of ±350 ppm. The crystal chosen for this design is 24 MHz and has a frequency stability of ±10 ppm, which is way lower than the maximum.

The design guide specifies that the stray capacitance can be assumed to be 1-2pF. However, since 10pF capacitors are used elsewhere on the PCB, 10pF capacitors are used for this design - which, when combined with the 8pF load capacitance of the crystal oscillator, leads to 3pF stray capacitance. This is still realistic for the PCB, but the capacitors can be replaced if needed.

---
### EEPROM Pins
> *Pins: TXD/SCK (31), RXD_SDA (27)*

The USB2244i supports an (optional) external EEPROM to program various configurations. However, this design does not implement the EEPROM, since it uses only the default configuration. Per the Hardware Design Checklist, if an EEPROM is not included, pull up resistors are still required. So, on both pins, 10kΩ pull up resistors are added, with no further connection to an EEPROM.

---
### Other Pins
> *Pins: RBIAS (35), LED (1), TEST (28), RESET_N (18)*

- RBIAS: Per the datasheet, this pin is pulled down by a 12kΩ±1% resistor to set up bias currents for internal circuitry. It must be placed as close as possible to the RBIAS pin, with a direct low impedance path to the ground plane.
- LED: The USB2244i has a pin to indicate media insertion/access to an LED. Since the MicroSD card is hidden internally in this application, an LED is not needed, and thus this pin is left floating.
- TEST: Per the datasheet, this pin must be tied to ground for normal operation.
- RESET_N: An active low reset signal to the USB2244i. Per the Hardware Design Guide, this pin should be pulled up by a 10kΩ resistor, with a 1uF decoupling capacitor to filter noise, if the reset is intended to be triggered by the power supply.

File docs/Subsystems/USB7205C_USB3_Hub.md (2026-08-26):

# USB7205C USB 3.2 Gen 2 5-port Hub Subsystem
## Preamble
The LAZARUS-1 Backplane PCB has several downstream USB devices (two SSDs, an SD card, a USB port for the LicheeRV Nano to emulate keyboard/mouse input, and a USB port to go to the external front panel USB hub). To ensure that they can all communicate with the host laptop device through a single USB-C port, and to ensure that data transfer speeds can be efficiently negotiated between each device, a USB hub is needed. The upstream USB-C port operates at USB 3.2 Gen 2 (10Gbps) speeds, with five downstream USB devices connected, and hence a 5-port USB 3.2 Gen 2 hub IC is needed.

The USB7205C was chosen for this purpose, for the following reasons:
1. Microchip has excellent student support (they give free samples for a lot of their products to students), and hence a hub IC from Microchip will not add to the BOM cost.
2. Of Microchip's offerings, the USB7205C is the only hub listed on their site that meets the requirements with no more than 5 ports. The other options include:
	1. USB7206C (the original chip used in this design), which is a higher binned variant of the USB7205C that has 6 ports instead of 5. However, since only 5 ports are needed, the extra 6th port is wasted and must have its traces tied to 3.3V, which increases routing complexity slightly. the USB7206 (non C) is also an option, however this is just an older revision of the same chip.
	2. USB7216C, which is similar to the USB7206C in that it has 6 downstream ports. However, it has USB Type-C support on downstream port 1, which introduces a few extra traces needed for USB Type-C (CC, SBU, etc.) - and these are not needed, as there are no downstream USB-C ports on this device. It also uses more power to run.

## Description
The USB7205C is a 5 port USB 3.2 Gen 2 Hub IC. It has one upstream USB 3.2 Gen 2 port (with both USB 3 and USB 2 lanes routed), and exposes four standard USB 3.2 Gen 2 downstream ports + one USB 2.0 downstream port. It supports FlexConnect (which allows any port to act as the upstream port), USB Bridging (converts USB to I2C, SPI, I2S, and GPIO), PortSwap (allows the differential USB 2.0 traces to be swapped in firmware), PHYBoost (USB redriving), VariSense (sensitivity tuning), and PortSplit (splitting USB 3 lanes from USB 2 lanes). All of these require custom programming through Microchip's MPLab software, which requires One-Time-Programming (OTP), external SPI flash memory, or SMBus (which requires an external MCU). To save on PCB space, an external SPI flash memory chip is not used. Instead, SMBus is used, connecting the USB7205C to an RP2350b MCU for configuration.

## Revision Progress

| Stages | USB7205C | LX7167A |
| --- | :---: | :---: |
| Initial Design | ✅ 2026-07-29 | ✅ 2026-07-25 |
| Basic Function Review/Documentation  | ✅ 2026-07-31 | ✅ 2026-07-30 |
| Extended Design Review/Documentation | | |
| Initial PCB layout | | |
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

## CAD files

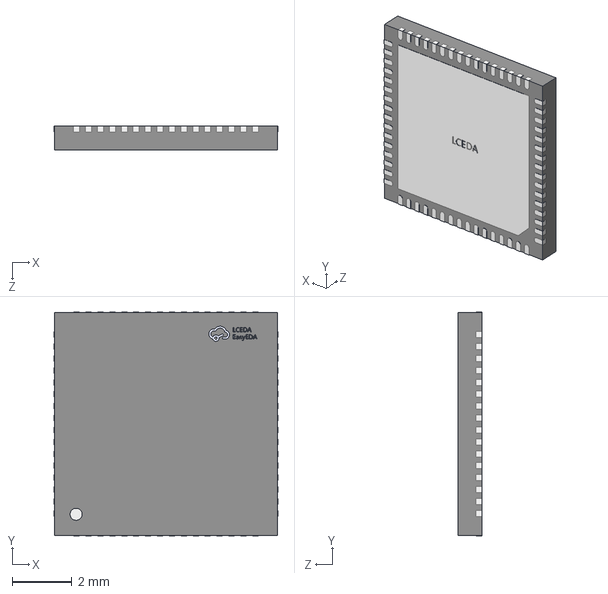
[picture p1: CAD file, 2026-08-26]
pcb_files/manually_imported_components/LT6911UXC/QFN-64_L7.5-W7.5-P0.40-TL-EP6.2.step
7.52 x 7.52 x 0.811 mm

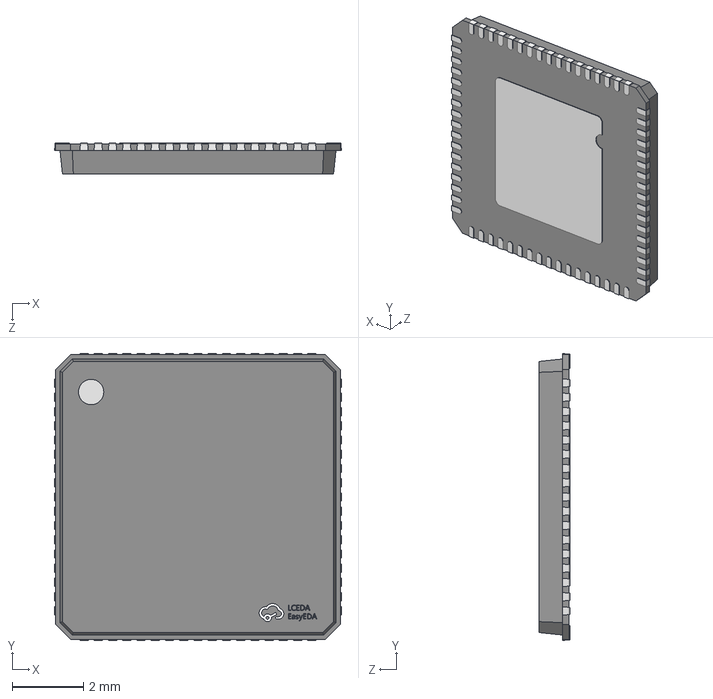
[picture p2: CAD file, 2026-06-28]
pcb_files/manually_imported_components/RTL9210B-CG/QFN-68_L8.0-W8.0-P0.40-BL-EP4.8.step
8.06 x 8.06 x 0.861 mm

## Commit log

2026-06-28 Made preliminary TUSB1064 schematic
    [BOM-serverv2_backplane.csv, QFN-68_L8.0-W8.0-P0.40-BL-EP4.8.step, dp_to_hdmi.kicad_sch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]
2026-07-03 Preliminary Revision of PS176 DP->HDMI Subsystem
    [dp_to_hdmi.kicad_sch, hdmi_to_csi.kicad_sch, serverv2_backplane.kicad_sch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]
2026-07-06 Preliminary draft of USB controller and power circuit
    [serverv2_backplane.kicad_sch, sg2002_and_rp2350b.kicad_sch, tusb1064.kicad_sch]
2026-07-09 Preliminary revision of USB hub and temperature monitor
    [other_connectors.kicad_sch, sata_connectors.kicad_sch, sd_card_slot.kicad_sch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]
2026-07-09 Preliminary design of USB2244i USB2.0 -> SD converter
    [dp_to_hdmi.kicad_sch, sd_card_slot.kicad_sch, tusb1064.kicad_sch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]
2026-07-10 Preliminary design of power monitor for PSU rails and USB-C VBUS
    [hdmi_to_csi.kicad_sch, other_connectors.kicad_sch, sata_connectors.kicad_sch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]
2026-07-11 Preliminary design of power monitor for PS176, TC358743, LicheeRV nano, and touch display
    [dp_to_hdmi.kicad_sch, hdmi_to_csi.kicad_sch, other_connectors.kicad_sch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]
2026-07-13 Preliminary design of power monitor for USB2244i, 2xRTL9210b + SSD, front panel hub, and 4x chassis fans
    [fan_control.kicad_sch, other_connectors.kicad_sch, sd_card_slot.kicad_sch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]
2026-07-13 Preliminary design of RTL9210b SSD subsystem
    [rtl9210b_circuit.kicad_sch, sensors.kicad_sch]
2026-07-13 Added CC pull up and pull down resistors for RTL9210b and added power switch for 5V rail for RTL9210b
    [rtl9210b_circuit.kicad_sch]
2026-07-19 Mostly complete initial transfer to hierarchical schematic
    [DISP_HEADER.kicad_sch, FAN_HEADER.kicad_sch, FPC_CONN.kicad_sch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]
2026-07-20 Transferred everything to hierarchical schematic and wired PSU power on circuit AND created duplicate schematics for all relevant subsystems
    [MCP6002.kicad_sch, PAC1954_FANS.kicad_sch, PAC1954_IPKVM_DISP.kicad_sch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]
2026-07-21 Cleaned up schematic and replaced TC358743XBG with reverse-engineered LT6911C
    [FPC_CONN.kicad_sch, LT6911UXC.kicad_sch, PSU_CONN.kicad_sch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]
2026-07-21 Cleaned up PS176 schematic and added some datasheets
    [PS176.kicad_sch, fan_control.kicad_sch, other_connectors.kicad_sch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]
2026-07-22 Basic function review and documentation for PS176 subsystem
    [PS176.kicad_sch, serverv2_backplane.kicad_sch]
2026-07-22 Added TVS clamping diodes to upstream USB-C port and fixed RX/TX orientation routing for entire system
    [RTL9210b_0.kicad_sch, SATA_PORT_DOWNSTREAM.kicad_sch, SATA_SUBSYSTEM.kicad_sch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]
2026-07-23 Basic Function Review and Documentation for TUSB1064 subsystem
    [LT6911UXC.kicad_sch, PS176.kicad_sch, serverv2_backplane.kicad_sch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]
2026-07-24 Small bug fixes to LT6911C subsystem to match official adapter model
    [LT6911UXC.kicad_sch, PS176.kicad_sch, tusb1064.kicad_sch]
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2026-07-25 Basic Function Review/Documentation for LT6911C Subsystem
    [LT6911UXC.kicad_sch, PS176.kicad_sch, SATA_PORT_DOWNSTREAM.kicad_sch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]
2026-07-26 Changed USB7206C's buck converter to LX7167
    [MCP6002.kicad_sch, TPS55288.kicad_sch, usb7206c.kicad_sch]
2026-07-28 Switched USB7206C IC to USB7205C
    [RP2350B_0.kicad_sch, USB7205C.kicad_sch, serverv2_backplane.kicad_sch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]
2026-07-30 Initial design of USB7205C
    [USB7205C.kicad_sch, serverv2_backplane.kicad_sch]
2026-07-30 Removed SPI flash from USB7205C
    [USB7205C.kicad_sch]
2026-07-31 Changed VCORE voltage of USB7205C to 1.15V
    [USB7205C.kicad_sch, serverv2_backplane.kicad_sch]
2026-07-31 Basic Function Review/Documentation of USB7205C
    [PORT4_USB.kicad_sch, RP2350B_0.kicad_sch, UCS2113.kicad_sch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]
2026-08-01 Added an (optional) RC network between shield pins of USB connector and GND
    [PORT5_USB.kicad_sch, upstream_usb-c.kicad_sch]
2026-08-01 Basic Function Review/Documentation of USB2244i
    [USB2244i.kicad_sch]
2026-08-04 Basic Function Review/Documentation of RP2354B
    [RP2354B_0.kicad_sch, SATA_PORT_DOWNSTREAM.kicad_sch, SG2002_HEADER.kicad_sch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]
2026-08-07 Basic Function Review/Documentation for TPS65987D
    [TPS55288.kicad_sch, TPS65987D.kicad_sch, serverv2_backplane.kicad_sch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]
2026-08-12 Updated EN/UVLO resistor divider for TPS55288 and removed 10 ohm series resistors for ISP/ISN
    [TPS55288.kicad_sch]
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2026-08-14 TPS55288: Added extra 220uF bypass capacitor on VOUT and connected SW1/SW2 properly
    [TPS55288.kicad_sch, serverv2_backplane.kicad_sch]
2026-08-14 Reorganized repo and created draft README
    [BOM-serverv2_backplane.csv, DISP_HEADER.kicad_sch, FAN_HEADER.kicad_sch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]
2026-08-16 Changed TPS55288 to internal droop compensation and added current monitoring for TPS55288 to ADC pin of LicheeRV Nano
    [SG2002_HEADER.kicad_sch, TPS55288.kicad_sch, serverv2_backplane.kicad_sch]
2026-08-16 Basic Function Review/Documentation for TPS55288
    [TPS55288.kicad_sch]
2026-08-17 Basic Function Review/Documentation for MCP9808
    [MCP9808.kicad_sch, PAC1954_FANS.kicad_sch, PAC1954_HUB.kicad_sch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]
2026-08-18 Switched PAC1954 to SLOW mode to save power
    [PAC1954_FANS.kicad_sch, PAC1954_HUB.kicad_sch, PAC1954_IPKVM_DISP.kicad_sch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]
2026-08-20 Added FAN4 and updated RP2354/PAC1954 to match
    [FAN_HEADER.kicad_sch, PAC1954_FANS.kicad_sch, PAC1954_HUB.kicad_sch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]
2026-08-20 Added ESD protection to fans
    [FAN_HEADER.kicad_sch, serverv2_backplane.kicad_sch]
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2026-08-31 Basic Function Review/Documentation for PAC1954 for IPKVM and Display
    [PAC1954_IPKVM_DISP.kicad_sch]
